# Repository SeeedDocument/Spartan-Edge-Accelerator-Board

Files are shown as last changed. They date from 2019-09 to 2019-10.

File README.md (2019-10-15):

---
name: Spartan Edge Accelerator Board
category: Platform
bzurl: 
oldwikiname: 
prodimagename:
surveyurl: 
sku: 102030005
tags:
---

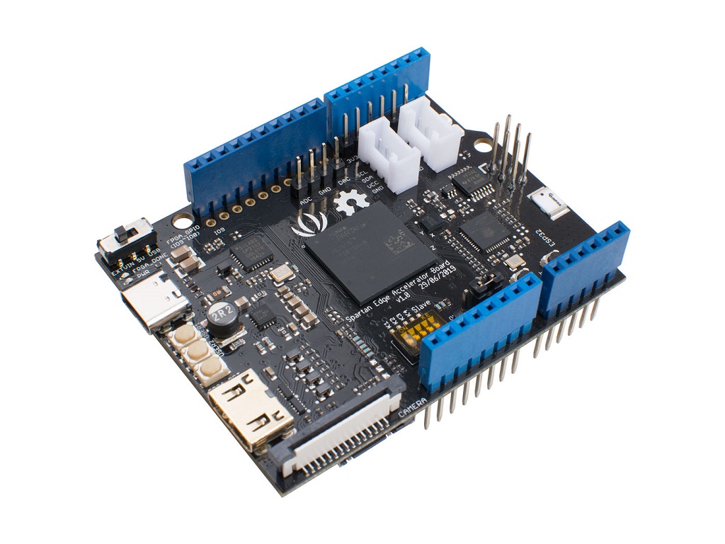
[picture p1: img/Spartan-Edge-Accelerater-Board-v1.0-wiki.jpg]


The Spartan Edge Accelerator Board (SEA Board in short) is a lightweight FPGA development board, it is based on the Xilinx Spartan-7 chip and follows the Arduino shield form factor. Hence, you can use it as an Arduino shield to driver an LCD and a camera or as a stand-alone FPGA development board. Besides, with the help of on-board ESP32 chip, the SEA board also enables your Arduino with WiFi and Bluetooth function.

**Spartan-7** is the newest and most cost-effective FPGA chip among Xilinx’s FPGA family, offers the best in class performance per watt. 

On top of that, we provide the full FPGA APIs for Arduino, which means Arduino users are able to use the FPGA function without knowing anything about FPGA. This board will broaden Arduino’s capability in many ways like simple image processing and computer vision application, signal encryption and decryption, and signal sampling and processing. 

## Features

- Full FPGA APIs for Arduino
- Stand alone mode/Arduino Shield mode
- On-board WiFi and bluetooth 4.1 with BLE
- On-board 8 bit ADC
- On-board 6 axis Accelerometer and Gyroscope
- On-board Grove Connector(I2C/D2)

## Specification

|Parameter|Value|
|---|---|
|**FPGA**||
|FPGA Chip|Spartan-7 XC7S15|
|Logic Cells|12,800|
|Slics|2000|
|CLB Flip-Flops|16,000|
|Max. Distributed RAM (Kb)|150|
|Block RAM/FIFO w / ECC (36 kb each)|10|
|Total Block RAM (Kb)|360|
|Clock Mgmt Tiles (1 MMCM + 1 PLL)|2|
|DSP Slices|20|
|**Wireless**||
|Wireless Chip|Espressif ESP32-D0WDQ6|
|WiFi |802.11 b/g/n 2.4GHz|
|Bluetooth|Bluetooth 4.1 with BLE|
|**Peripheral**||
|Video|Mini HDMI x1|
|Camera|CSI/MIPI interface x1 (compatible with Raspberry Pi Camera V1 - OV5640)|
|SD card|Micro SD/TF card slot x1|
|FPGA GPIO|10 pins header (IO9~IO0)|
|Arduino GPIO|32 pins header (Arduino form factor)|
|Grove|Grove Connector x2 (I2C/D2)|
|LED|Monochrome LED x2<br>RGB LED x2|
|Button|Boot x1<br> Reset x1<br> FPGA Reset x1 <br> User x2|
|Switch|Power Mode Switch x1<br>5-Channel DIP Switch x1|
|**Power**||
|Operating Voltage|5V|
|IO Voltage|5V|
|Power Mode|USB Type C 5V<br>VIN 8~17V<br>Arduino Micro USB 5V|
|**Others**||
|ADC|8 bit ADC1173|
|Accelerometer and Gyroscope|6-axis LSM6DS3TR |

!!!Attention
    The SEA shield's IO voltage is 5V, and the FPGA's IO voltage is 3.3V, so we made a voltage divider to make the IOs voltage compatible. The 3.3V IO voltage of the SAM D21 series will be less than 3.3V after voltage division, which is not enough to drive the FPGA's IO. Therefore, at present, the SEA development board only supports the 5V IO Arduino board, such as [Arduino UNO](https://www.seeedstudio.com/Arduino-Uno-Rev3-p-2995.html) and [Seeeduino V4.2](https://www.seeedstudio.com/Seeeduino-V4-2-p-2517.html).

## Hardware Overview

<div align="center">
<figure>
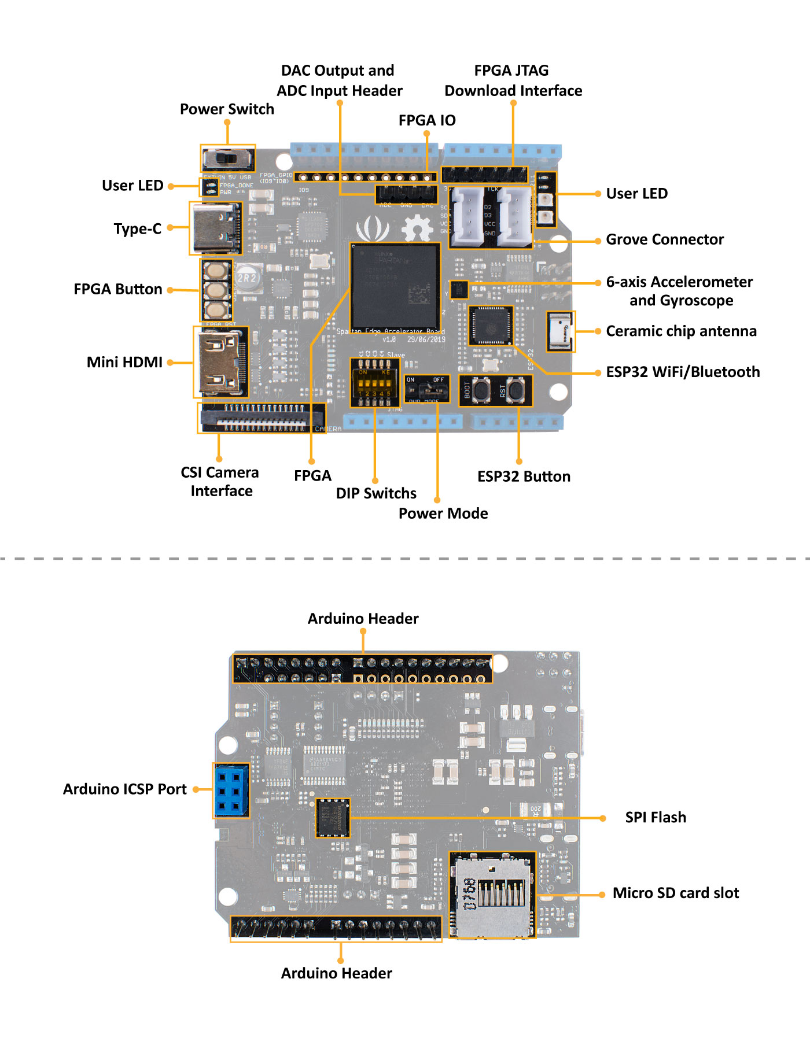
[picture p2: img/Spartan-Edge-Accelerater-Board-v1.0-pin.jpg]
Hardware Overview of SEA Board
  <a href="https://raw.githubusercontent.com/SeeedDocument/Spartan-Edge-Accelerator-Board/master/img/Spartan-Edge-Accelerater-Board-v1.0-pin.jpg" target="_blank">
  <figcaption><b>Figure 1</b>. <i>Hardware Overview of SEA Board</i></figcaption></a>
</figure>
</div>

|Number|Detail|
|-----|---|
|1.|FPGA : XC7S15-1FTGB196C|
|2.|WiFi/Bluetooth : ESP32-D0WDQ6|
|3.|6-axis Accelerometer and Gyroscope : LSM6DS3TR |
|4.|DAC : DAC7311IDCKR|
|5.|Buck-DCDC : TPS62130|
|6.|USB-to-UART : CP2102-GMR|
|7.|USB : Type-C |
|8.|Mini HDMI|
|9.|CSI Interface ：MIPI Camera (compatible with Raspberry Pi Camera V1 - OV5640)|
|10.|Arduino Header : Compatible with Arduino UNO|
|11.|DIP Switchs :<br>K1-K4 user switchs<br>K5 Switch FPGA Programming Mode <br>  ->>>> JTAG : Using Xilinx official Programming Tool<br>->>>> Slave : [Using ESP32 to Program the FPGA](https://github.com/sea-s7/spartan-edge-esp32-boot) |
|12.|ESP32 Button ：Boot and RST|
|13.|FPGA Button ：USER1 USER2 FPGA_RST|
|14.|User LED: L1/L2/RGB1/RGB2<br>PWR : Power On <br> FPGA_DONE : Light up after programming the FPGA with esp32.|
|15.|Power Switch :<br> USB->Powered by USB Type C (5V DC)<br>5V->Powered by VIN Pin (8~17V DC)|
|16.|Power Mode:<br>OFF->Isolate the power supply of Arduino and Shield<br>ON->Connect Power of Arduino and Shield|
|17.|DAC Output and ADC Input Header|
|18.|FPGA IO : IO9~IO0|
|19.|FPGA JTAG Download Interface|
|20.|Grove Connector : 1x I2C; 1x D2&D3|
|21.|Ceramic chip antenna|
|22.|ADC : ADC1173|
|23.|SPI Flash : W25Q32JVZPIG|
|24.|Analog Switch ：DG2788A|
|25.|LDO : XC6221B102MR|
|26.|LDO : RT9013-18GB|
|27.|LDO : CJ1117-3V3|
|28.|SD card slot : Micro SD/TF card|

## Getting Started

Spartan Edge Accelerator Board can work in two modes:

- Arduino shield Mode
- Stand-alone Mode

In brief, it can work as a Arduino shield to bring the Arduino FPGA and Wireless features, it also can work as a FPGA development board without an Arduino. 

### Arduino shield Mode

In this wiki, we use Seeeduino V4.2, you can also use Arduino UNO, they are fully compatible with each other.

#### Hardware

**Materials required**

- [Seeeduino V4.2](https://www.seeedstudio.com/Seeeduino-V4-2-p-2517.html) x1 
- [Spartan Edge Accelerator Board]() x1
- [Micro SD card or TF card](https://www.seeedstudio.com/micro-SD-Card-Card-with-Card-Reader-32GB-Class-10-p-4082.html) x1
- [USB Type C data cable](https://www.seeedstudio.com/USB-Type-C-to-A-Cable-1Meter-p-4085.html) x1

**Hardware Connection**

- Step1. Insert the Micro SD card or TF card into the SD card slot
- Step2. Plug the SEA Board into the Arduino
- Step3. Use one of the following three methods to power the system

|Power Port|Input Voltage|Power Switch Position|Power Mode Position|
|---|---|---|---|
|Powered by SEA board USB Type C port| 5V DC|USB|ON|
|Powered by Seeeduino V4.2 micro USB port| 5V DC|--|ON| 
|Powered by Seeeduino V4.2 DC port| 8~17V DC|5V|ON|

<div align="center">
<figure>
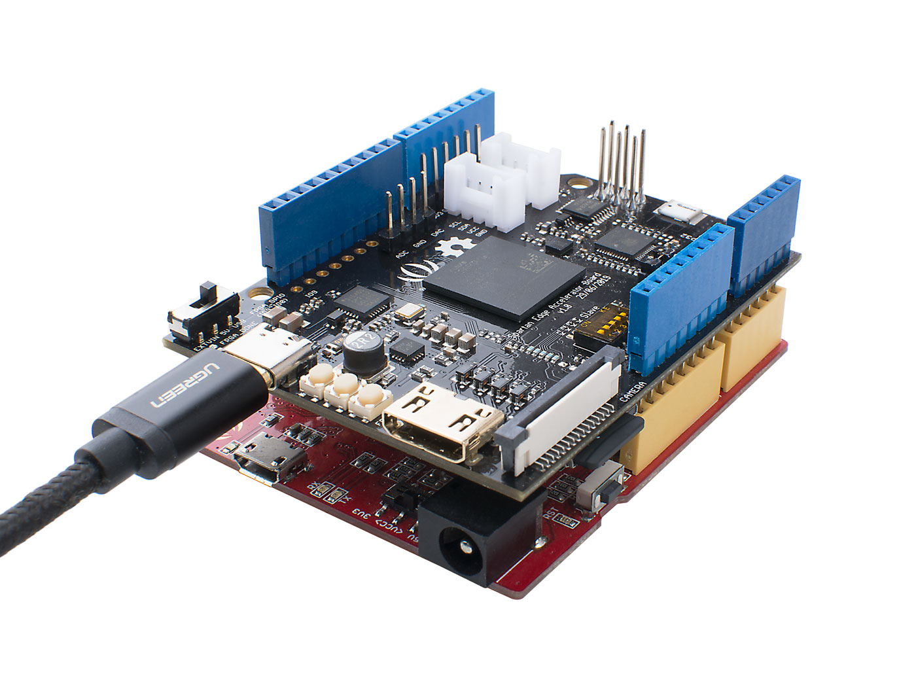
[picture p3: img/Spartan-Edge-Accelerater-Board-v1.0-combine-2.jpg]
Spartan Edge Accelerator Board Work with Arduino
  
  <figcaption><b>Figure 2</b>. <i>SEA board Work with Arduino</i></figcaption>
</figure>
</div>

!!!Attention
    You can also power both the SEA board and the Arduino at the same time, but please make sure you have set the Power Mode Position to **OFF**. Only then, the system power will be isolated, and you can power the Arduino and SEA board separately.

-------

#### Spartan Edge Accelerator Board ESP32 Boot

Firstly, to work with Arduino, we should load bitstream(FPGA Logic) from SD Card to the on-board FPGA(xc7s15). The following library will show you how to do this via on-board ESP32.

a library for Spartan Edge Accelerator Board

The purpose of this library is to load bitstream(FPGA Logic) from SDCard to the on-board FPGA(xc7s15) by the on-board ESP32.

The software development environment is [Arduino IDE](https://www.arduino.cc/en/Main/Software) with [ESP32 Boards support](https://github.com/espressif/arduino-esp32).

Since Version 1.6.4, Arduino allows installation of third-party platform packages using Boards Manager. We have packages available for Windows, Mac OS, and Linux (32 and 64 bit).

- Install the current upstream Arduino IDE at the 1.8 level or later. The current version is at the [Arduino website](http://www.arduino.cc/en/main/software).
- Start Arduino and open Preferences window.
- Enter ```https://dl.espressif.com/dl/package_esp32_index.json``` into *Additional Board Manager URLs* field. You can add multiple URLs, separating them with commas.
- Open Boards Manager from Tools > Board menu and install *esp32* platform (and don't forget to select your ESP32 board from Tools > Board menu after installation).
- select ___tool->board->DOIT ESP32 DEVKIT___   

Stable release link: `https://dl.espressif.com/dl/package_esp32_index.json`  
Development release link: `https://dl.espressif.com/dl/package_esp32_dev_index.json`  
If you want more details, you can click the [link](https://github.com/espressif/arduino-esp32)

<br>

##### Library Usage

- **1.Download the ESP32 Boot Library**

<div align="center">
<figure>
  
</figure>
</div>

Then add this library to your Arduino IDE.

If you don't know how to install the library, please kindly check:  
 
 [Installing Additional Arduino Libraries](https://www.arduino.cc/en/Guide/Libraries)

 You can find two example folders in this library

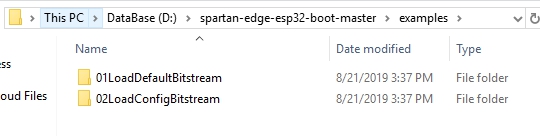
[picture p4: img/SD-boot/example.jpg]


|Example|Description|
|----|----|
|01LoadDefaultBitstream |This example will load SDCard file /overlay/default.bit to FPGA|
|02LoadConfigBitstream |This example will read a ini format file /board_config.ini in SDCard,then load the bitstream spcified by the value of key **overlay_on_boot** to FPGA.|

- **2.Prepare SDCard**  
  2.1 Format the SDCard with FAT16/FAT32 filesystem.  

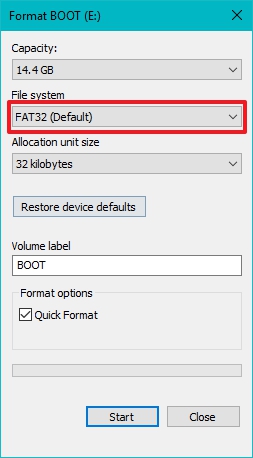
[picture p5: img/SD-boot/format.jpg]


  2.2 Create a top level subfolder named __overlay__ in the SDCard.  
  2.3 Put your bitstream or [sample bitstream](https://github.com/sea-s7/AlphaTest_V1.0/tree/master/spi2gpio) files (must have a extend name .bit) into the folder __overlay__.  

!!!Tip
    The sample bitsteam : GPIO extension controlled by SPI interface, with support of ADC/DAC/RGB-LED, see [source code](https://github.com/sea-s7/Demo_project/tree/master/spi2gpio).

  2.4 If you run example 01LoadDefaultBitstream, rename the bitstream file in __overlay__ to __default.bit__.  



  2.5 If you run example 02LoadConfigBitstream, put [**board_config.ini**](https://github.com/sea-s7/spartan-edge-esp32-boot/blob/master/extras/board_config.ini) into SDCard root folder.  
  2.6 Insert the SDCard to the Spartan (Edge Accelerator) Board.  

- **3.Upload example**  
  3.1 Connect the Spartan Board through USB Type-C wire to the PC, and install USB232 driver (chip CP2102).  
  3.2 Turn the power switch (near the USB Type-C slot) to USB side to power on the board.  
  3.3 Open one of the library examples by Arduino IDE.  
  3.4 Check Board & Port setting in Arduino IDE as described in last section.  
  3.5 Press 'BOOT' Button on Sparton Board and last more than 1 seconds to force ESP32 enter Bootloader mode.  
  3.6 Press 'Upload' button in Arduino IDE to upload the example ('s compiled binary) to ESP32.  

- **4.Run example**  
  4.1 Make sure the on-board DIP-switch K5 (last one) on Slave(ON) side, which enable FPGA programing by other device(MCU).  
  4.2 Press 'RST' button on Spartan Board to startup the example.  
  4.3 After the example bootup a few seconds, the FPGA_DONE(red color) LED on the board will light on.

------

#### Spartan Edge Accelerator Board IO Example

Then, the following tutorial will show you how to control the GPIO/ADC/DAC/RGB-LED resources of Spartan Edge Accelerator Board with Arduino.

- Download the IO Example Library:

<div align="center">
<figure>
  
</figure>
</div>

- Add this library to your Arduino IDE. If you don't know how to install the library, please kindly check:  

 [Installing Additional Arduino Libraries](https://www.arduino.cc/en/Guide/Libraries)

- Located to the `examples` folder, choose any example, double cilck the .ino file.

- Upload the demo. If you do not know how to upload the code, please check [How to upload code](http://wiki.seeedstudio.com/Upload_Code/).

### Stand-alone Mode

#### Hardware

**Materials required**

- [Spartan Edge Accelerator Board]() x1
- [USB Type C data cable](https://www.seeedstudio.com/USB-Type-C-to-A-Cable-1Meter-p-4085.html) x1

Just power the Spartan Edge Accelerator Board via the USB Type C cable.

#### Software

Spartan Edge Accelerator Board can also work as a traditional FPGA development board. The following traditional will show you how to use it at the stand-alone mode.

In this section, you will learn about the Project mode features for project creation, source file management, design analysis, constraint definition, and synthesis and implementation run management. This could be used as a quick reference.

First of all, you should download the vivado tutorial library, we will need some sorce files.

<div align="center">
<figure>
  
</figure>
</div>

- **Step 1: Creating a Project**   

  *Launching Vivado*

  *Creating a New Project*

1. After Vivado opens, select **Create Project** on the Getting Started page.

2. Click **Next** in the New Project wizard

3. Specify the Project Name and Location (Select “**Create project subdirectory**” to create a folder for your project) 

4. Click **Next**.

5. Select **RTL Project** as the **Project Type** and click **Next**.(Select **Do not specify sources at this time** and add your files soon afterwards)

   *(The Vivado Design Suite allows for different design entry points depending on your source file types and design tasks. You can choose the suitable type of project.)*

6. Select the **xc7s15ftgb196-1** part for project, and click Next, as shown in figure 1.

7. Click **Finish**

<div align="center">
<figure>
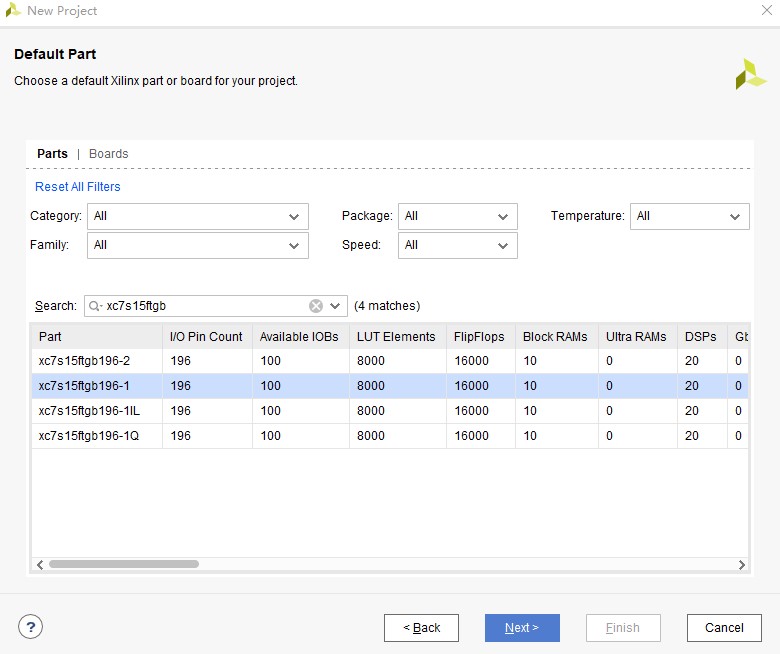
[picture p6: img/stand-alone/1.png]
  
    <div class="text"><b>Figure 1.</b></div>
</figure>
</div>

The Vivado IDE opens project_tutorial in the default layout, as shown in figure 2.

<div align="center">
<figure>
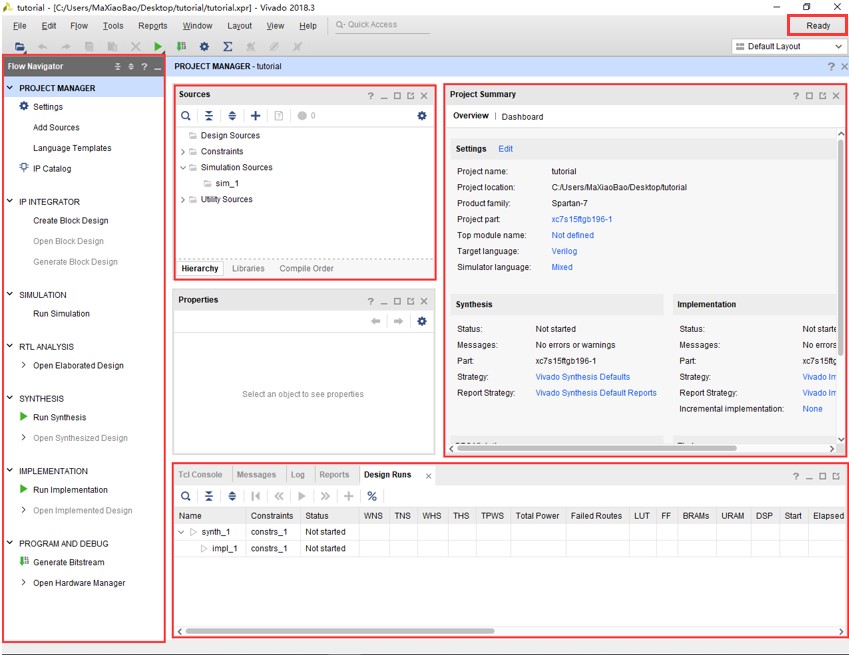
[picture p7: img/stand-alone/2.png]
  
  <div class="text"><b>Figure 2.</b></div>
</div>

The **Flow Navigator** shows the basic design process clearly.

The **Sources** is made up of **Constraints**, **Simulation** **Sources** and **Utility** **Sources**.

The **Design Runs** creates synth_1 and impl_1 by default.

The **running status** of vivado is displayed in the upper right corner.

- **Step 2: Add and Create Your Files** 

  *in this step, we add **test.v** , **test_pin.xdc** , **test_sim.v** in our project. These files are located in different folders of **vivado_tutorial/vivado_tutorial.srcs*** 

1. Click **Add Sources** in the **PROJECT MANAGER** of the Flow **Navigator** to add **RTL file**.

2. Select **Add or create design sources** and click Next.

3. Click the button  and select options or click the options directly to add or create files, as shown in figure 3.

<div align="center">
<figure>
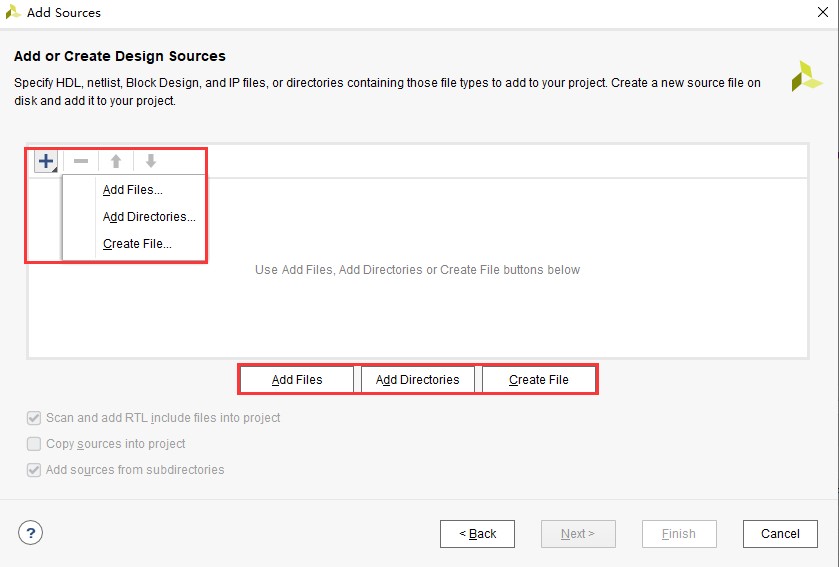
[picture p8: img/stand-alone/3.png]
  
  <div class="text"><b>Figure 3.</b></div>
</figure>
</div>

4. Here, we add RTL files directly. Select **Add Files** and add file **test.v** in your directory, as shown in figure 4.

<div align="center">
<figure>
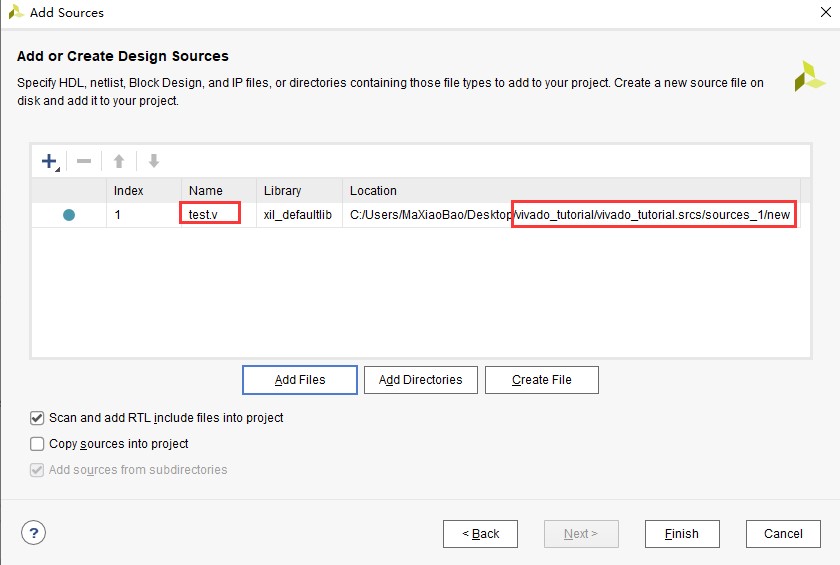
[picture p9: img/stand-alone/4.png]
  
  <div class="text"><b>Figure 4.</b></div>
</figure>
</div>

5. Click **Finish**.

6. Click **Add Sources** in the **PROJECT MANAGER** of the Flow **Navigator** again to add **constraints file**.

7. Select **Add or create constraints** and click Next. 

8. Click **Add Files** and add your constraints file **test_pin.xdc** ,as shown in figure 5

    <div align="center">
    <figure>
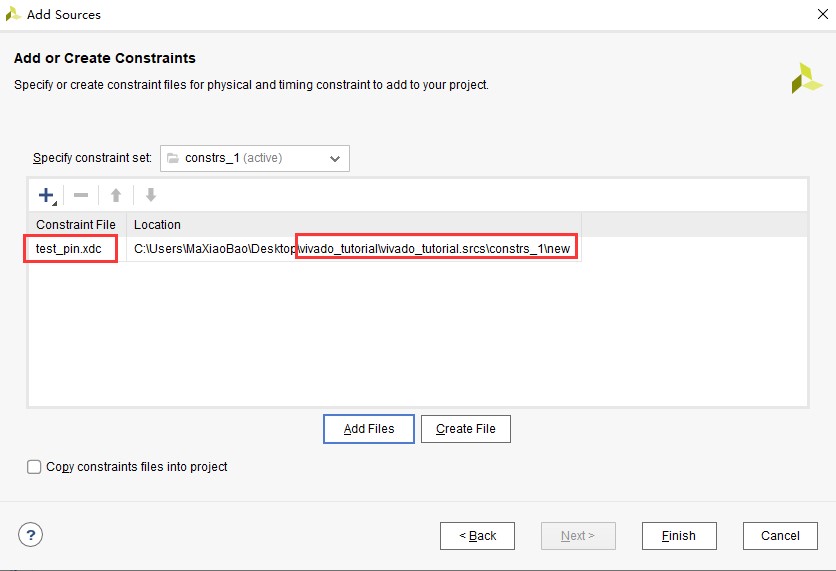
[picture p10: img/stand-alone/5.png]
      
      <div class="text"><b>Figure 5.</b></div>
    </figure>
    </div>

9. Click **Finish**.

10. Click **Add Sources** in the **PROJECT MANAGER** of the Flow **Navigator** again to add **simulation file**.

11. Select **Add or create simulation sources** and click Next. 

12. Click **Add Files** and add your simulation file **test_sim.v** ,as shown in figure 6

     <div align="center">
     <figure>
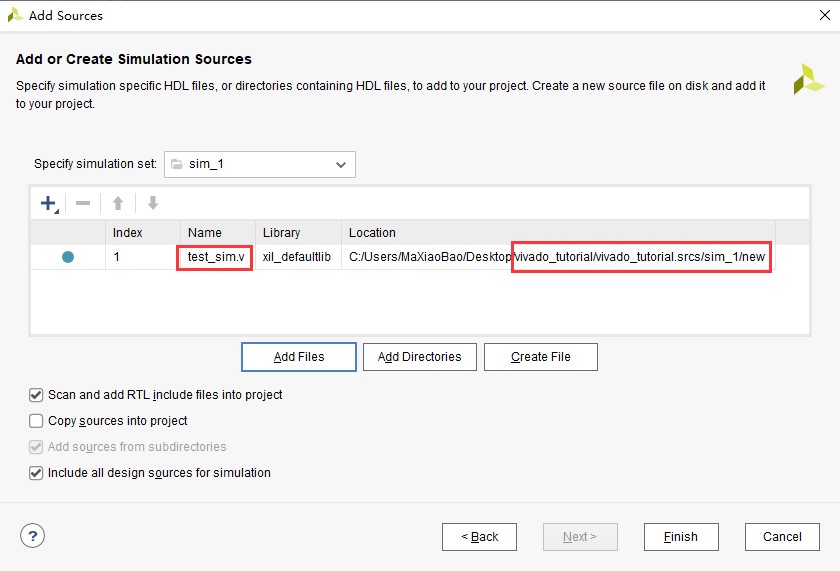
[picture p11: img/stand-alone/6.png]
       
       <div class="text"><b>Figure 6.</b></div>
     </figure>
     </div>

13. Click **Finish**.

     Finally, the file we added will appear in the **Sources**, as shown in figure 7.

<div align="center">
<figure>
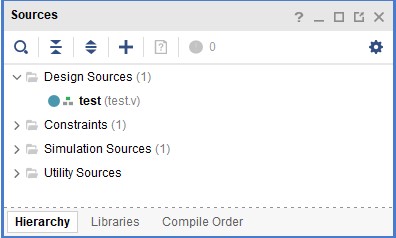
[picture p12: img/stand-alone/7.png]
  
   <div class="text"><b>Figure 7.</b></div>
</figure>
</div>

- **Step 3: Elaborating the RTL Design**

  The Vivado IDE includes an RTL analysis and IP customizing environment. There are also several RTL Design Rule Checks (DRCs) to examine ways to improve performance or power on the RTL design.

1. Select Open Elaborated Design in the Flow Navigator to elaborate the design.

2. Ensure that the Layout Selector pull down menu in the main Toolbar has Default Layout selected. The Elaborated Design enables various analysis views including an RTL Netlist, Schematic, and Graphical Hierarchy. The views have a cross-select feature, which helps you to debug and optimize the RTL.

3. Explore the logic hierarchy in the RTL Netlist window and examine the Schematic. You can traverse the schematic by double-clicking on cells to push into the hierarchy, or by using commands like the Expand Cone or Expand/Collapse from the Schematic popup menu. 

4. Select any logic instance in the Schematic and right-click to select the **Go to Source** or **Go to Definition** commands.

5. Click the Messages window at the bottom of the Vivado IDE, and examine the messages.

6. Click the **Collapse All** button in the Messages toolbar.

7. Expand the Elaborated Design and the messages, as shown in figure 8.

<div align="center">
<figure>
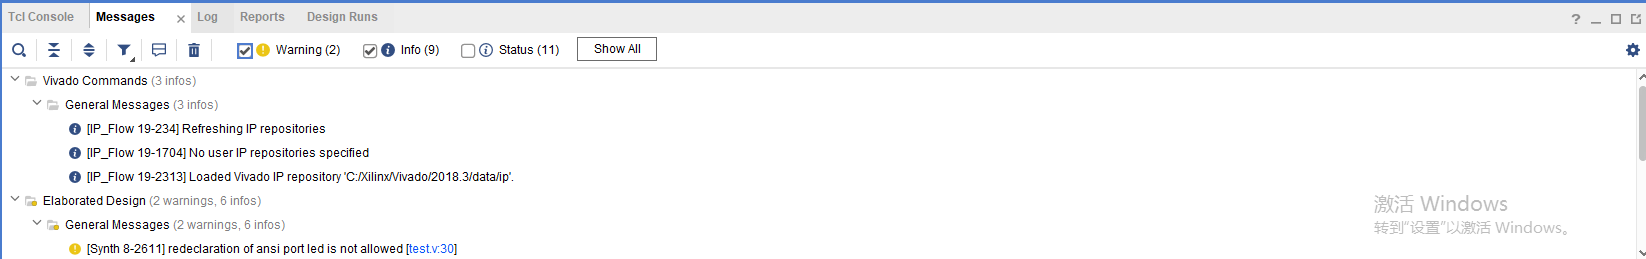
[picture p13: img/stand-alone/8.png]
  
   <div class="text"><b>Figure 8.</b></div>
</figure>
</div>

8. Click one of the links and the Text Editor opens the RTL source file with the relevant line highlighted.
9. Close the Text Editor windows.
10. Close the Elaborated Design by clicking on the **X** on the right side of the Elaborated Design window banner, and click OK to confirm.

- **Step 4: Using the IP Catalog**

  The Xilinx IP Catalog provides access to the Vivado IP configuration and generation features. You can sort and search the Catalog in a variety of ways. IP can be customized, generated, and instantiated.

1. Click the **IP Catalog** button in the Flow Navigator, under Project Manager.

2. Browse the IP Catalog to examine the various categories and IP filtering capabilities.

3. Choose the corresponding IP and perform native customization and configuration of IP within the tool and select **OK**

4. Close the IP Catalog tab by clicking on the X on the window tab.

- **Step 5: Running Behavioral Simulation**

  The Vivado IDE integrates the Vivado Simulator, which enables you to add and manage simulation sources in the project. You can configure simulation options, and create and manage simulation source sets. You can run behavioral simulation on RTL sources, prior to synthesis.

1. In the Flow Navigator, under Project Manager, click the Settings command. The Settings dialog box opens with Project Settings at the top, and Tool Settings below that, as shown in figure 9.

<div align="center">
<figure>
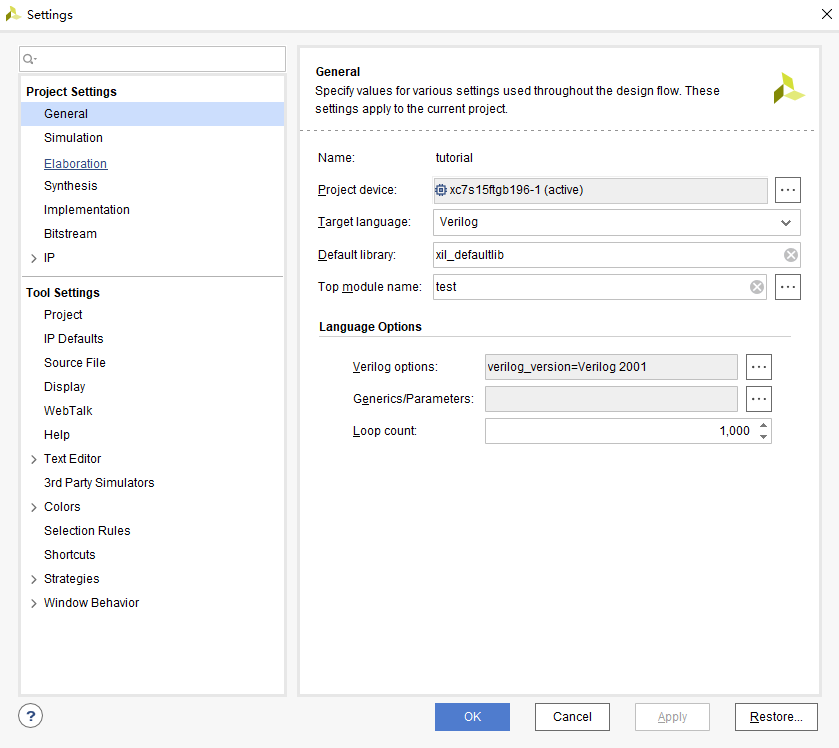
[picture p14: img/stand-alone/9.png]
  
  <div class="text"><b>Figure 9.</b></div>
</figure>
</div>

2. Examine the settings available on the **Simulation** page, then click **Cancel** to close the dialog box.
3. Click the **Run Simulation** command in the Flow Navigator, then click the **Run Behaviora Simulation** in the sub-menu, as shown in figure 10.

<div align="center">
<figure>
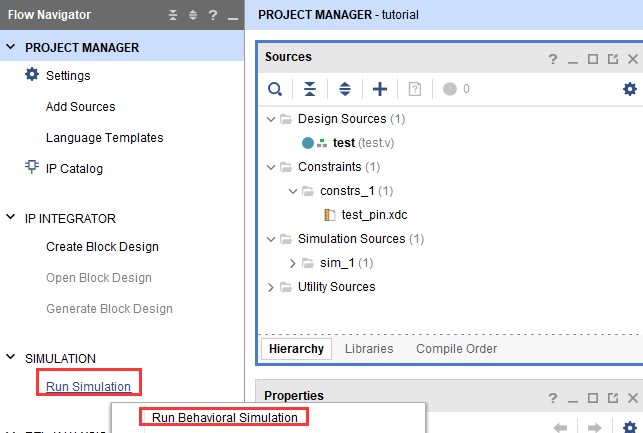
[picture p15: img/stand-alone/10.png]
  
  <div class="text"><b>Figure 10.</b></div>
</figure>
</div>

4. Drag the bar to the left and use these tools to zoom in or zoom out to see the appropriate image, as shown in figure 11 and figure 12.

   <div align="center">
   <figure>
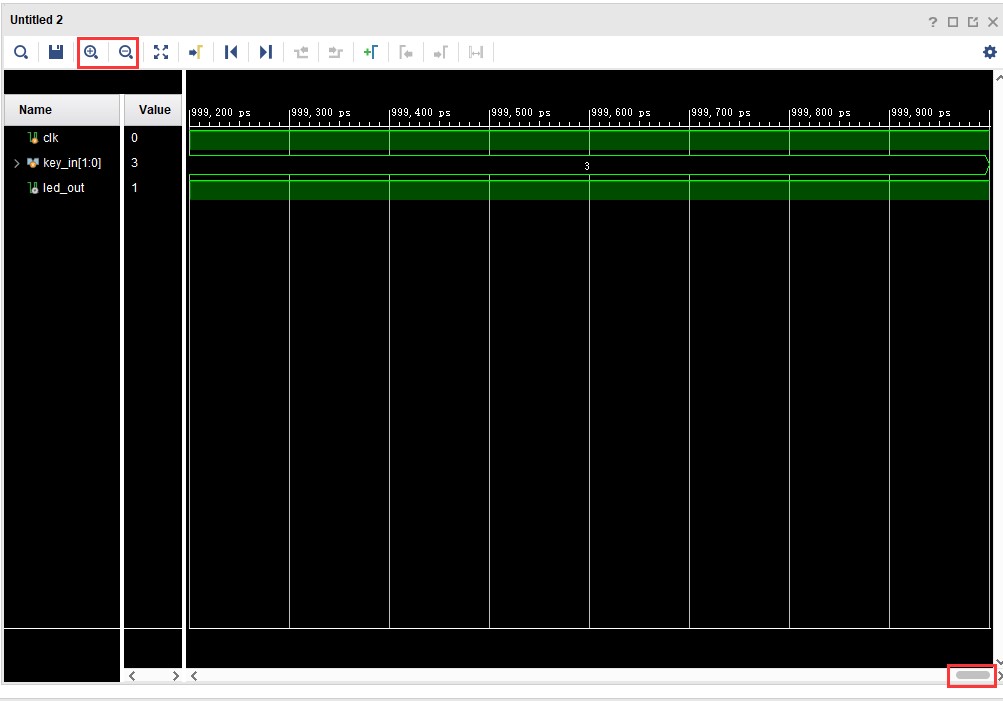
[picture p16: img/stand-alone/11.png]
     
     <div class="text"><b>Figure 11.</b></div>
   </figure>
   </div>

   <div align="center">
   <figure>
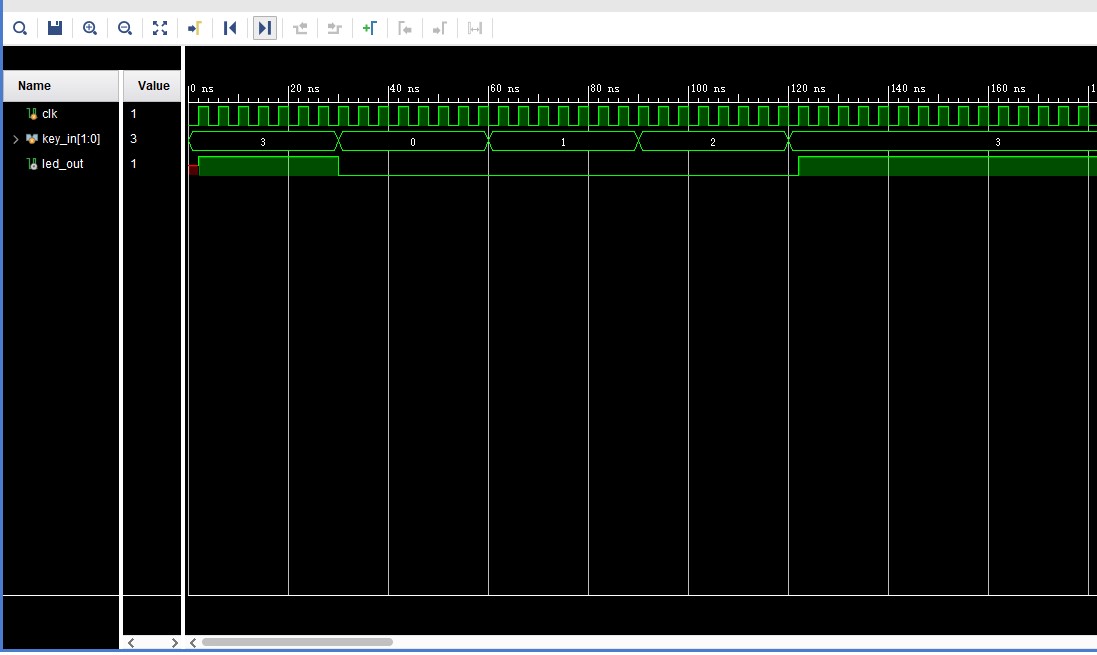
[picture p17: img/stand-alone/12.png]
     
     <div class="text"><b>Figure 12.</b></div>
   </figure>
   </div>

5. Click **X** on the Right-Up corner of figure 13 and click **OK** to close the SIMULATION.

   <div align="center">
   <figure>
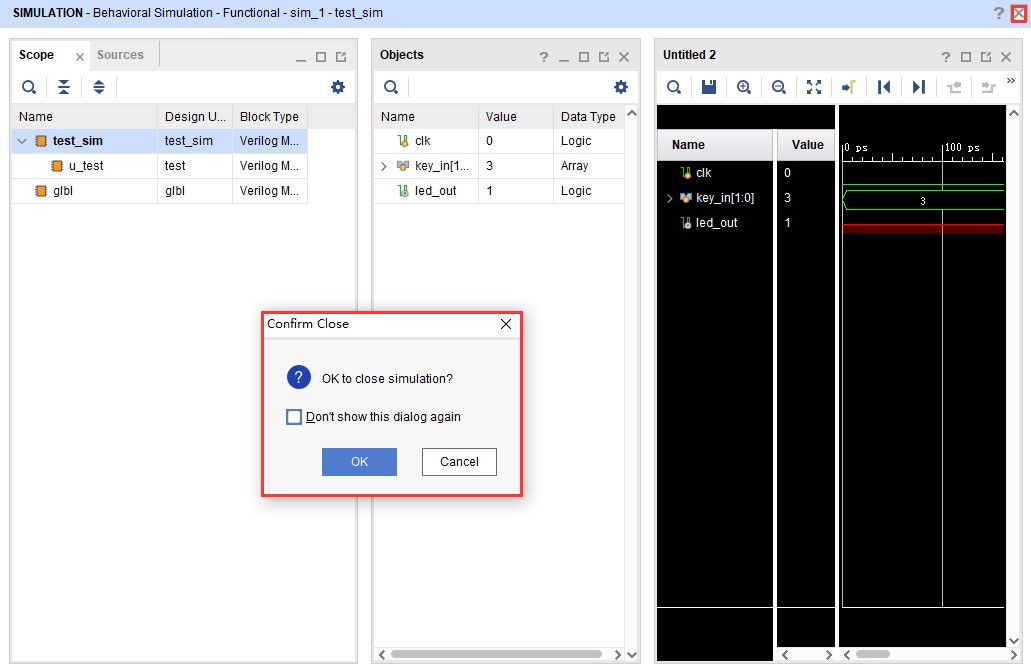
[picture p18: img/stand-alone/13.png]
     
     <div class="text"><b>Figure 13.</b></div>
   </figure>
   </div>

- **Step 6:  Reviewing Design Run Settings**

  Design runs are a way of configuring and storing the many options available in the different steps of the synthesis and implementation process. You can configure these options and save the configurations as strategies to be used in future runs.

1. In the Flow Navigator, under Project Manager, click the **Settings** command.

2. Select the **Synthesis** page under Project Settings. For a complete description of these options, see the *Vivado Design Suite User Guide: Synthesis*([UG901](https://www.xilinx.com/support/documentation/sw_manuals/xilinx2018_3/ug901-vivado-synthesis.pdf)).

3. Select the **Implementation** page under Project Settings. For a complete description of these options, see the *Vivado Design Suite User Guide: Implementation*([UG904](https://www.xilinx.com/support/documentation/sw_manuals/xilinx2018_3/ug904-vivado-implementation.pdf )).

- **Step 7: Synthesizing and Implementing the Design**

  After configuring the synthesis and implementation run options, you can **run synthesis** and **run implementation** in the **Design Runs** or click the button   or click corresponding buttons in the **Flow Navigator** to do this. The **running status** of vivado is displayed in the upper right corner while Synthesizing and Implementing.

	For this tutorial, we will run these steps in the Design Runs.

1. Right click the syth_1 and select **Launch Runs**, as shown in figure 14.

<div align="center">
<figure>
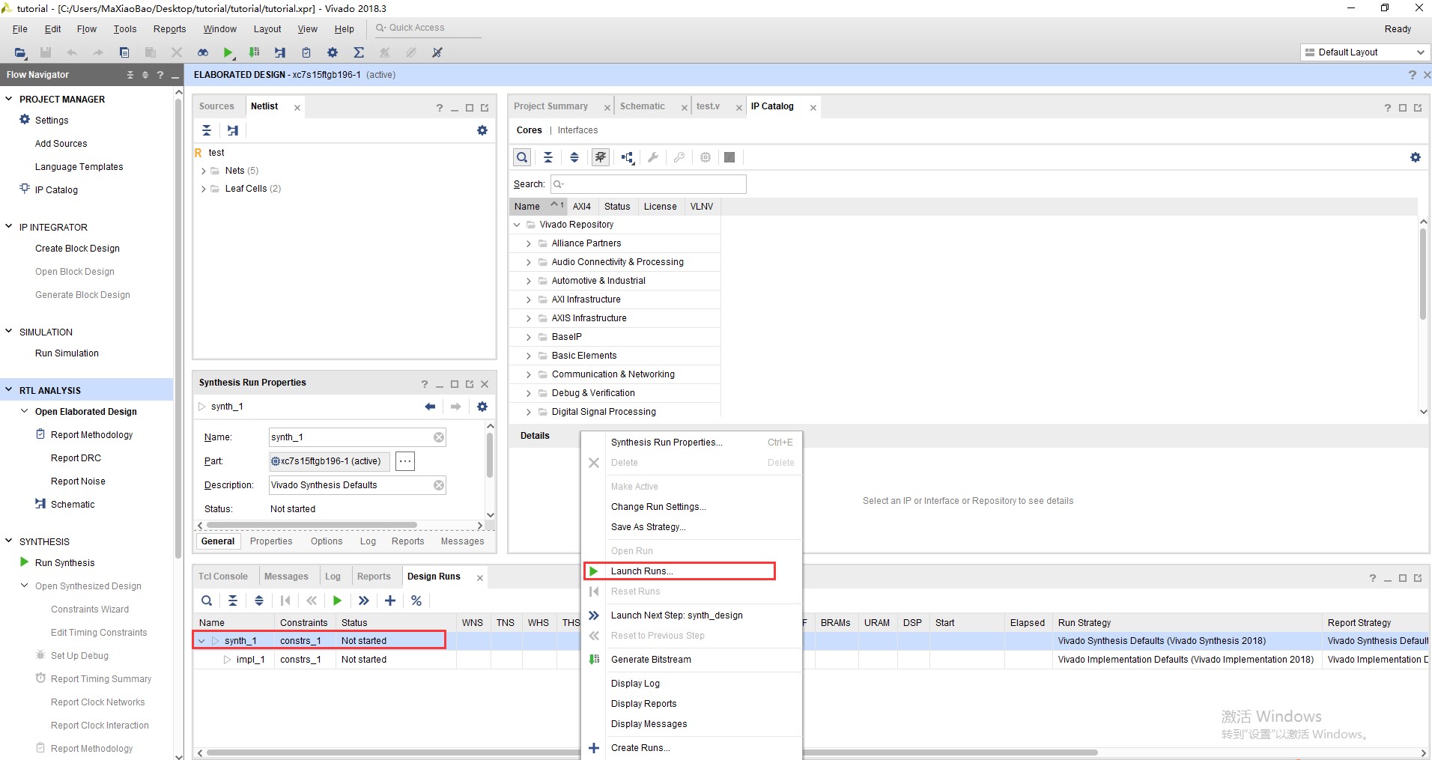
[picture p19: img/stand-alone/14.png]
  
  <div class="text"><b>Figure 14.</b></div>
</figure>
</div>

2. Click ok and running status is displayed in the upper right corner, as shown in figure 15.

<div align="center">
<figure>
  
  <div class="text"><b>Figure 15.</b></div>
</figure>
</div>

3. Click  **Open Synthesized Design** for further design and analysis. You can see **Report Timing Summary** , **Report Utilization** and others, as shown in figure 16.

<div align="center">
<figure>
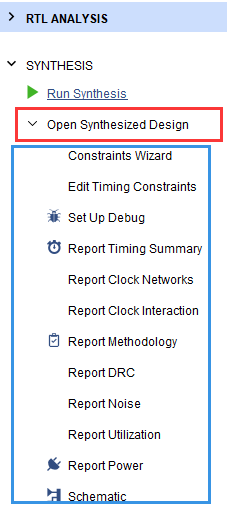
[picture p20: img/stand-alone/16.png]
  
  <div class="text"><b>Figure 16.</b></div>
</figure>
</div>

4. Run Implementation in the same way, as shown in figure 17.

<div align="center">
<figure>
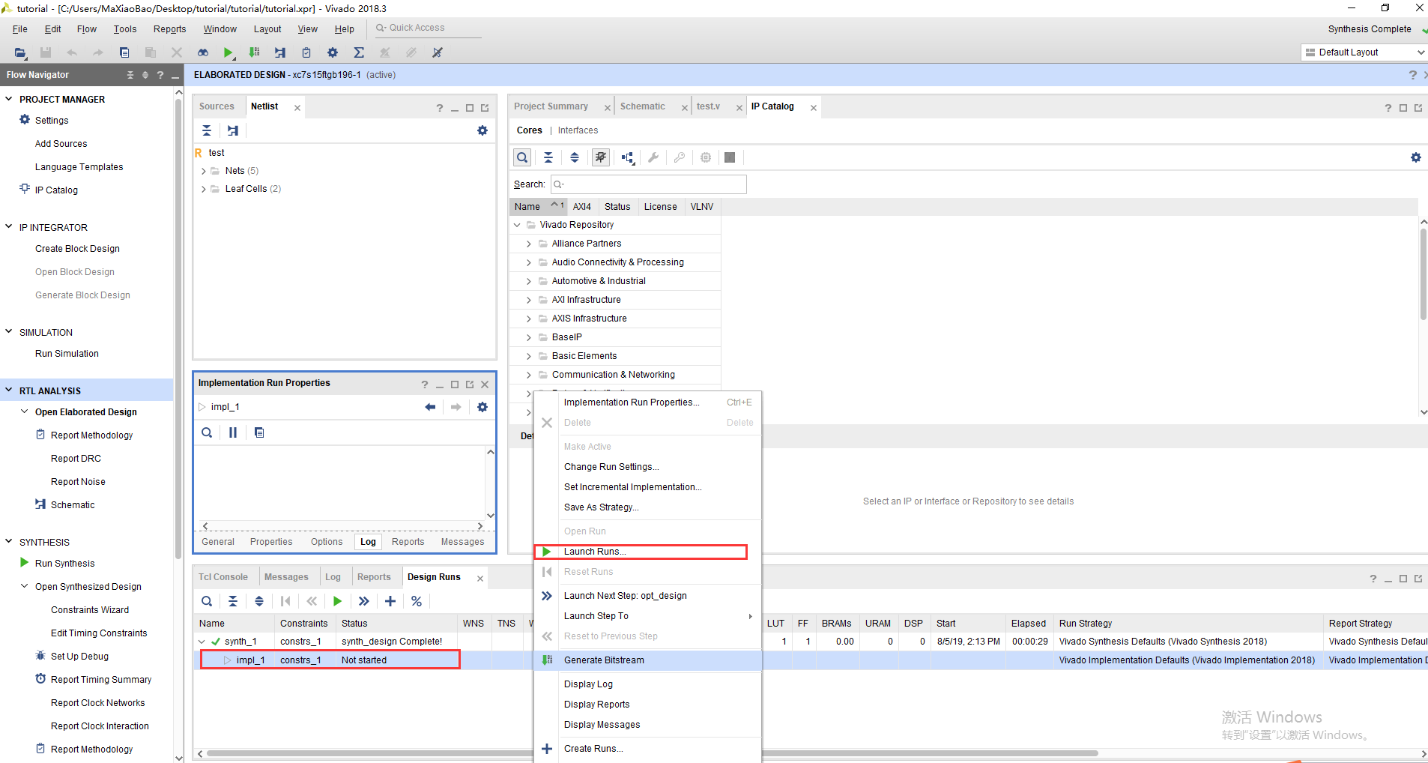
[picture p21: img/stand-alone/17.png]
  
  <div class="text"><b>Figure 17.</b></div>
</figure>
</div>

5. Click **Open implemented Design** to see reports after implementation 

- **Step 8: Generating a Bitstream File**

  After **Implementing the Design,** we can see synthesis and implement Complete in the **Design Runs**,as shown in figure 18.

<div align="center">
<figure>
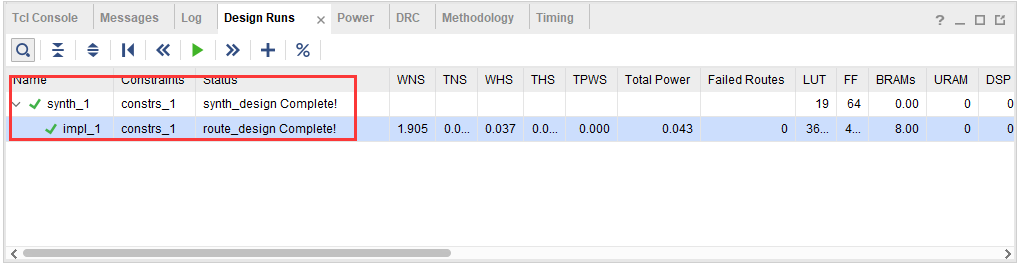
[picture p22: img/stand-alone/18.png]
  
  <div class="text"><b>Figure 18.</b></div>
</figure>
</div>

 Click **Generate Bitstream** in the Flow Navigator.

- **Step 9: Download the file** 

  After **Generate Bitstream,** you have two ways to load the file to FPGA. 

  You can use the JTAG interface(on the Right-Up corner of figure 19) to load the bit file to FPGA  in vivado, or    use the ESP32 (on the Right-Down corner of figure 19) to load the bit file to FPGA.

<div align="center">
<figure>
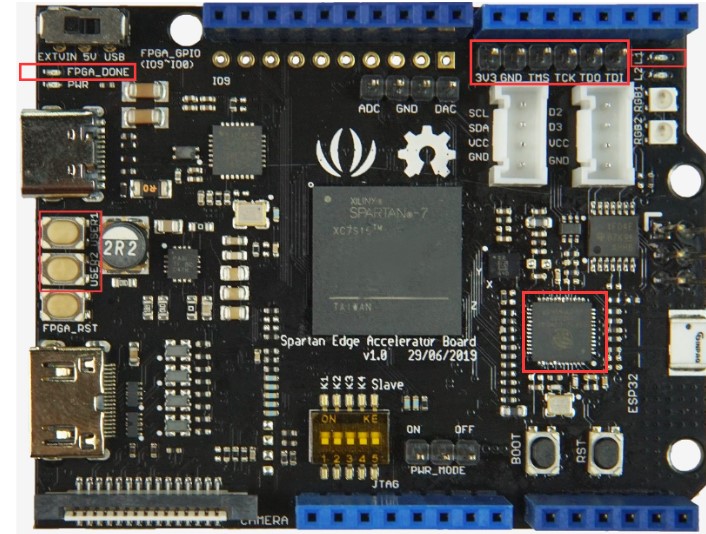
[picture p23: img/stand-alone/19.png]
  
  <div class="text"><b>Figure 19.</b></div>
</figure>
</div>

  **Follow below steps, to load bitstream to FPGA through JTAG interface**

1. Power the board and connect the [Platform Cable USB II](https://www.xilinx.com/products/boards-and-kits/hw-usb-ii-g.html)  (Or Compatible Cable).

2. Click **Open Target** and **Auto Connect** in the Flow Navigator.

3. While connect to the board successfully, click **Program Device** and choose the bit file and click **Program**, as shown in figure 20

<div align="center">
<figure>
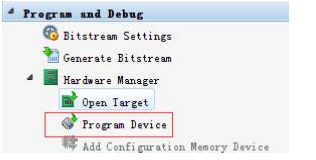
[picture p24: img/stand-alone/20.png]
  
  <div class="text"><b>Figure 20.</b></div>
</figure>
</div>

1. After download the bit file, the **FPGA**_**DONE** **led** will light.

   *In this project, if you press any key or both of them(**USER1** and **USER2**),  **LED L1**  will go out.*

## Resources

- **[PDF]** [Spartan-7 FPGAs Datasheet](https://github.com/SeeedDocument/Spartan-Edge-Accelerator-Board/raw/master/res/Spartan-7%20FPGAs%20Data%20Sheet.pdf)
- **[PDF]** [ESP32 Datasheet](https://github.com/SeeedDocument/Spartan-Edge-Accelerator-Board/raw/master/res/ESP32-datasheet.pdf)

## Tech Support
Please submit any technical issue into our [forum](http://forum.seeedstudio.com/).

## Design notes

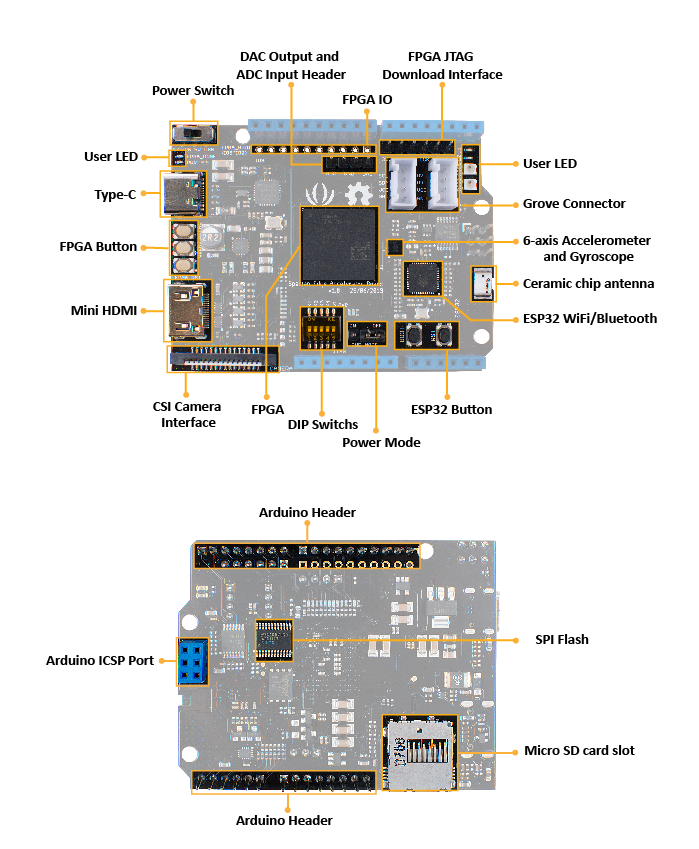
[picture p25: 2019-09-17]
img/hardware-overview.png

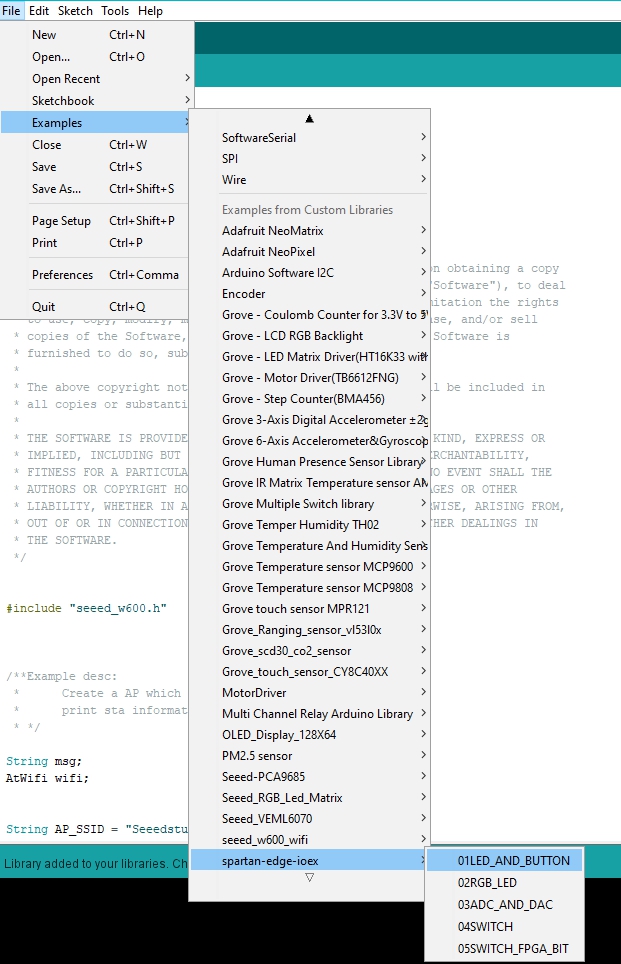
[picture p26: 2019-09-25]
img/IO-ex/example.jpg

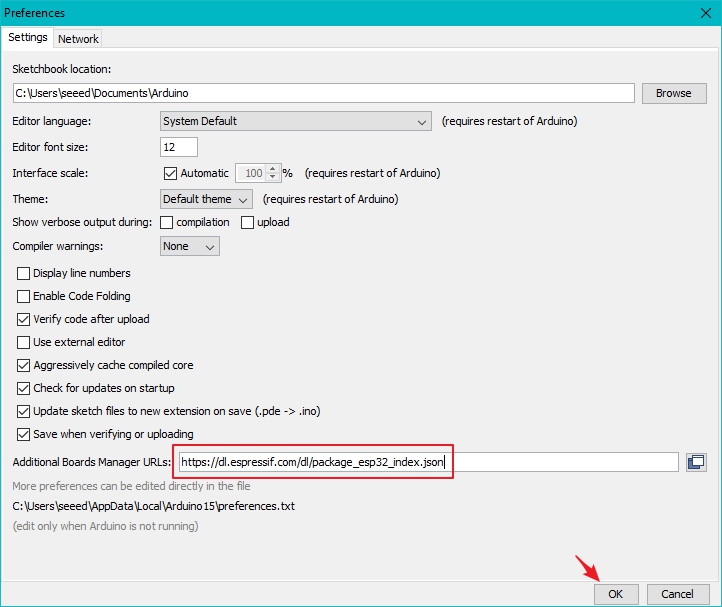
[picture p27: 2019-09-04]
img/boot-IDE-1.jpg

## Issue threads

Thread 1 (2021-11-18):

https://github.com/sea-s7 repository does not exist

richardklingler, 2021-11-18:
This board uses the spi2gpio Vivado design and the Wiki references to this repo:

https://github.com/sea-s7

But this repository doesn't seem to exist..so without the spi2gpio sources this board is useless!

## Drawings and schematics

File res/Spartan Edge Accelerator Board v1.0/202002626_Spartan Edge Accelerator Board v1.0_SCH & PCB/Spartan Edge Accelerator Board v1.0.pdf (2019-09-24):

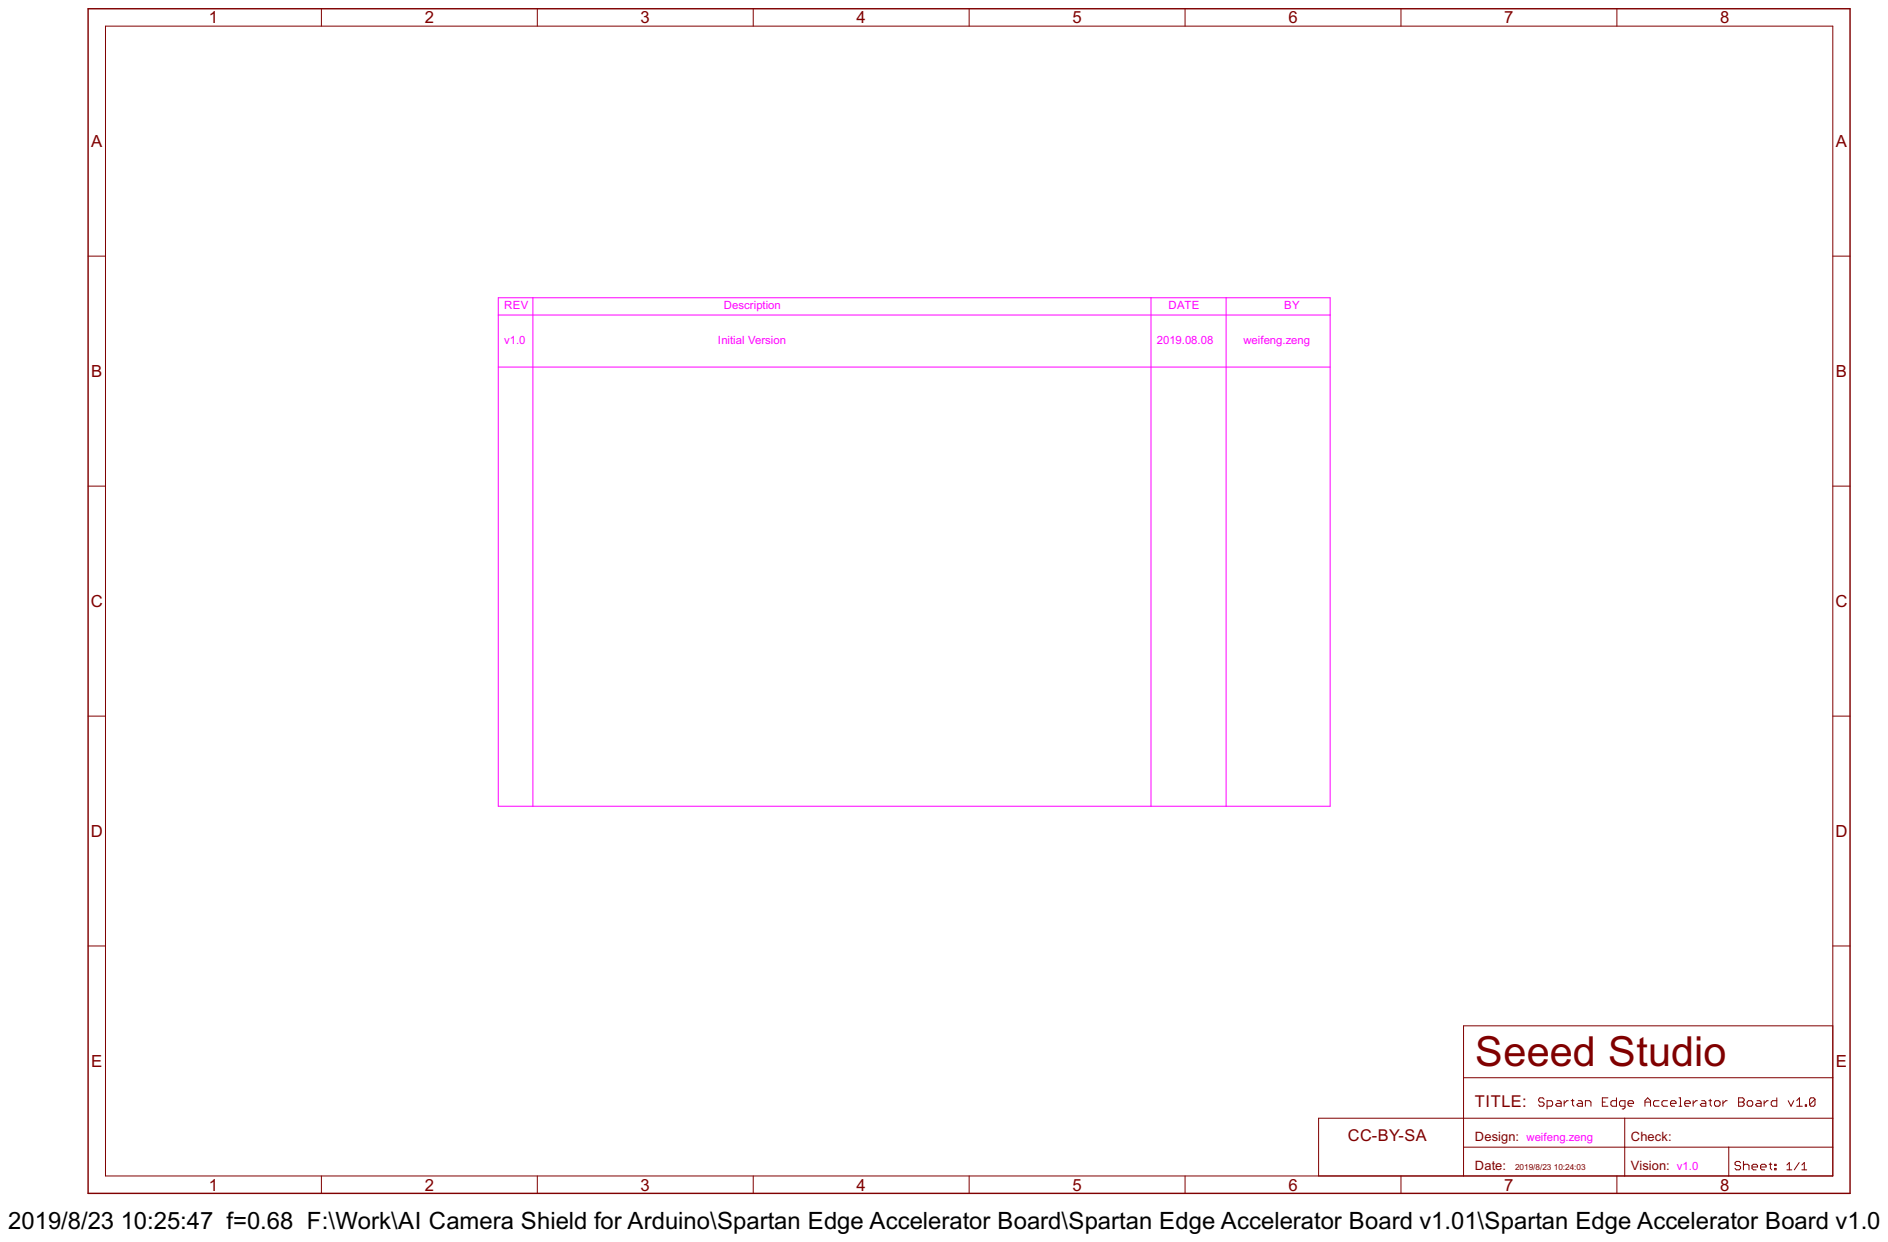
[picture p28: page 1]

REV | Description | DATE | BY

v1.0 | Initial Version | 2019.08.08 | weifeng.zeng

TITLE: Design: weifeng.zeng | Check: Date: Vision: CC-BY-SA

2019/8/23 10:25:47 f=0.68 F:\Work\AI Camera Shield for Arduino\Spartan Edge Accelerator Board\Spartan Edge Accelerator Board v1.01\Spartan Edge Accelerator Board v1.0\202002626_Spartan Edge Accelerator Board v1.0_SCH & PCB\Spartan Edge Accelerator Board v1.0.sch (Sheet: 1/1)

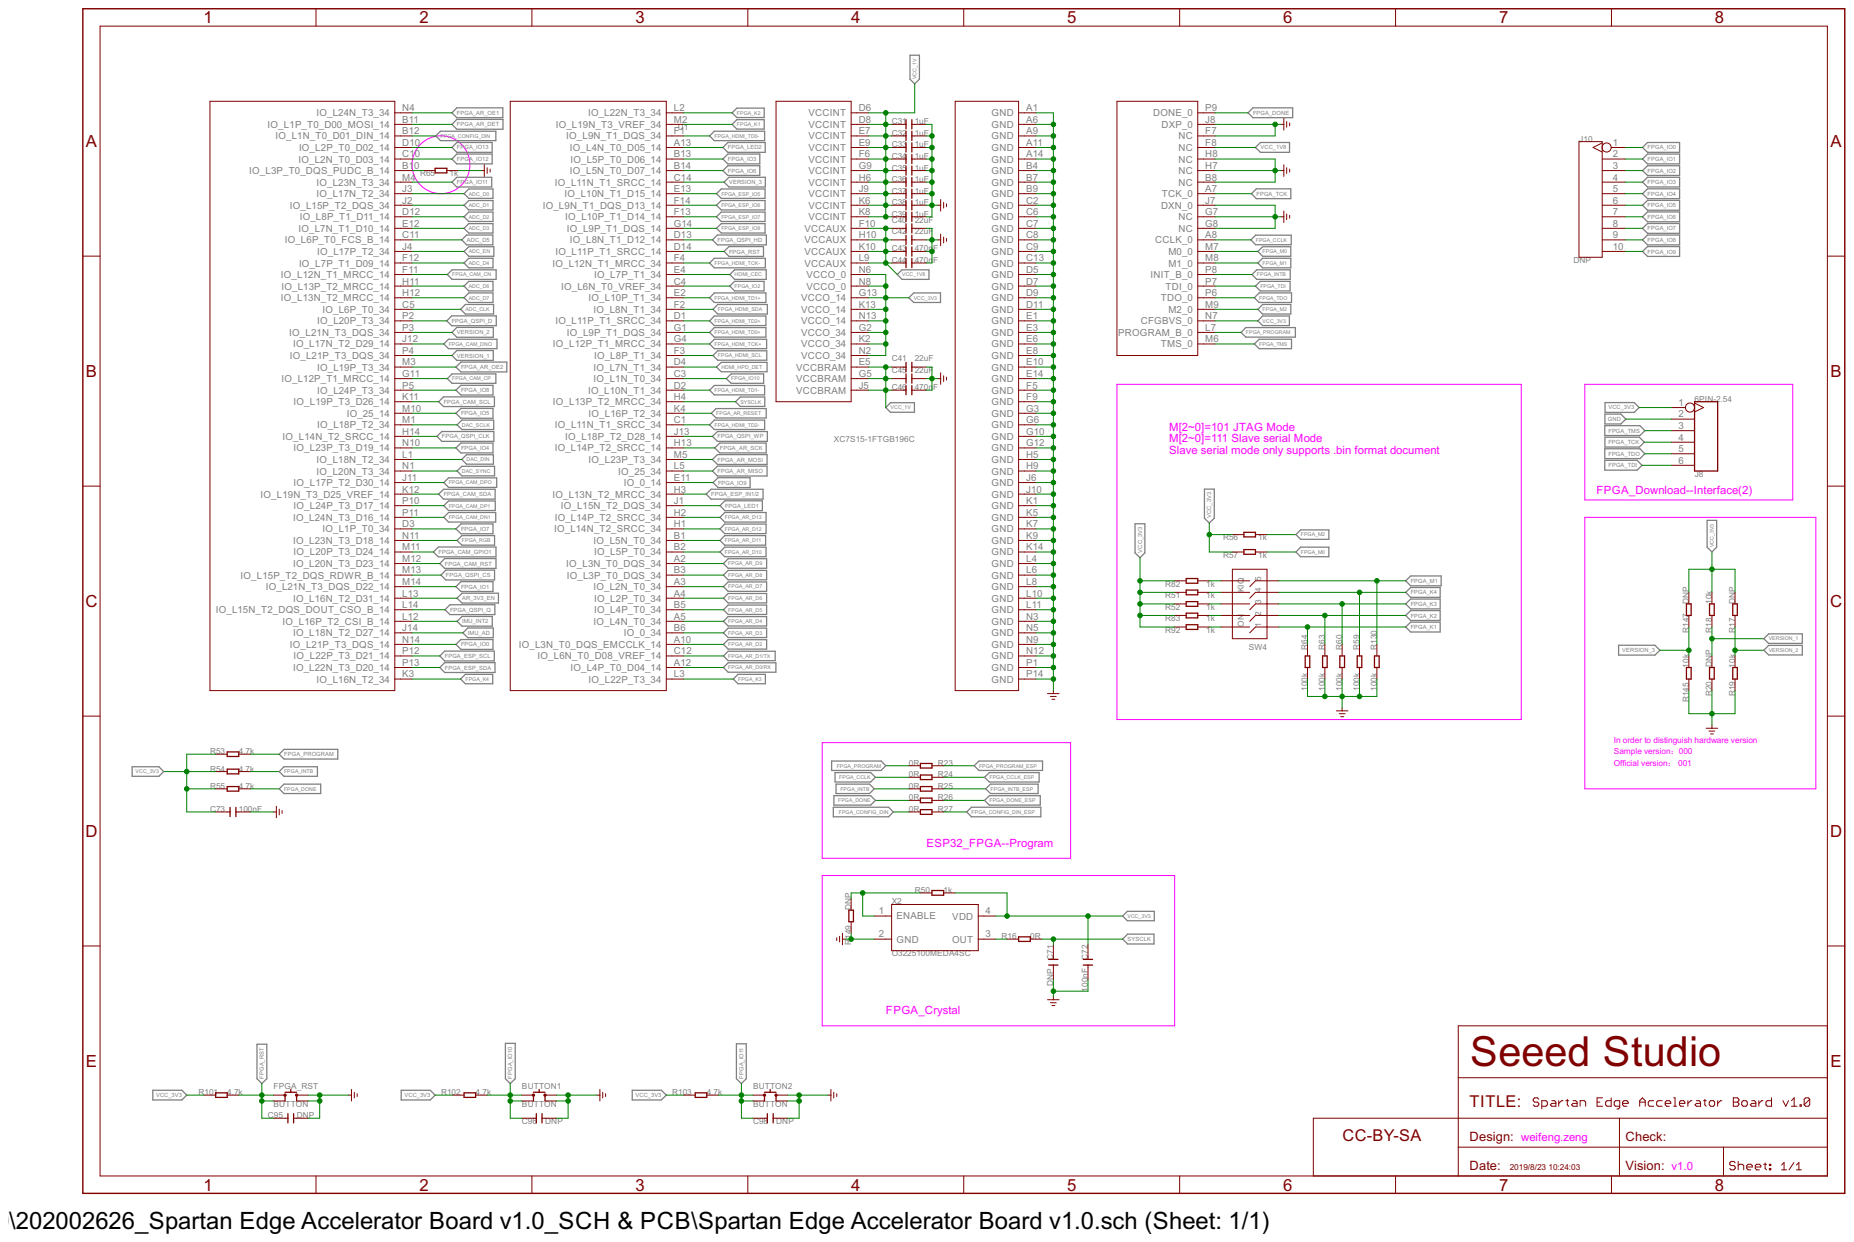
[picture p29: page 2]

SYSCLK FPGA_HDMI_TD2-FPGA_AR_D8 FPGA_AR_D7 FPGA_AR_D6 FPGA_AR_D5 FPGA_AR_D4 FPGA_AR_D3 FPGA_AR_D2 FPGA_AR_D1/TX FPGA_AR_D0/RX L3 | VCC_1V

FPGA_Download--Interface(2) M[2~0]=101 JTAG Mode M[2~0]=111 Slave serial Mode Slave serial mode only supports .bin format document

In order to distinguish hardware version
Sample version：000
Official version： 001

TITLE: Design: | Check: Date: Vision: CC-BY-SA

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

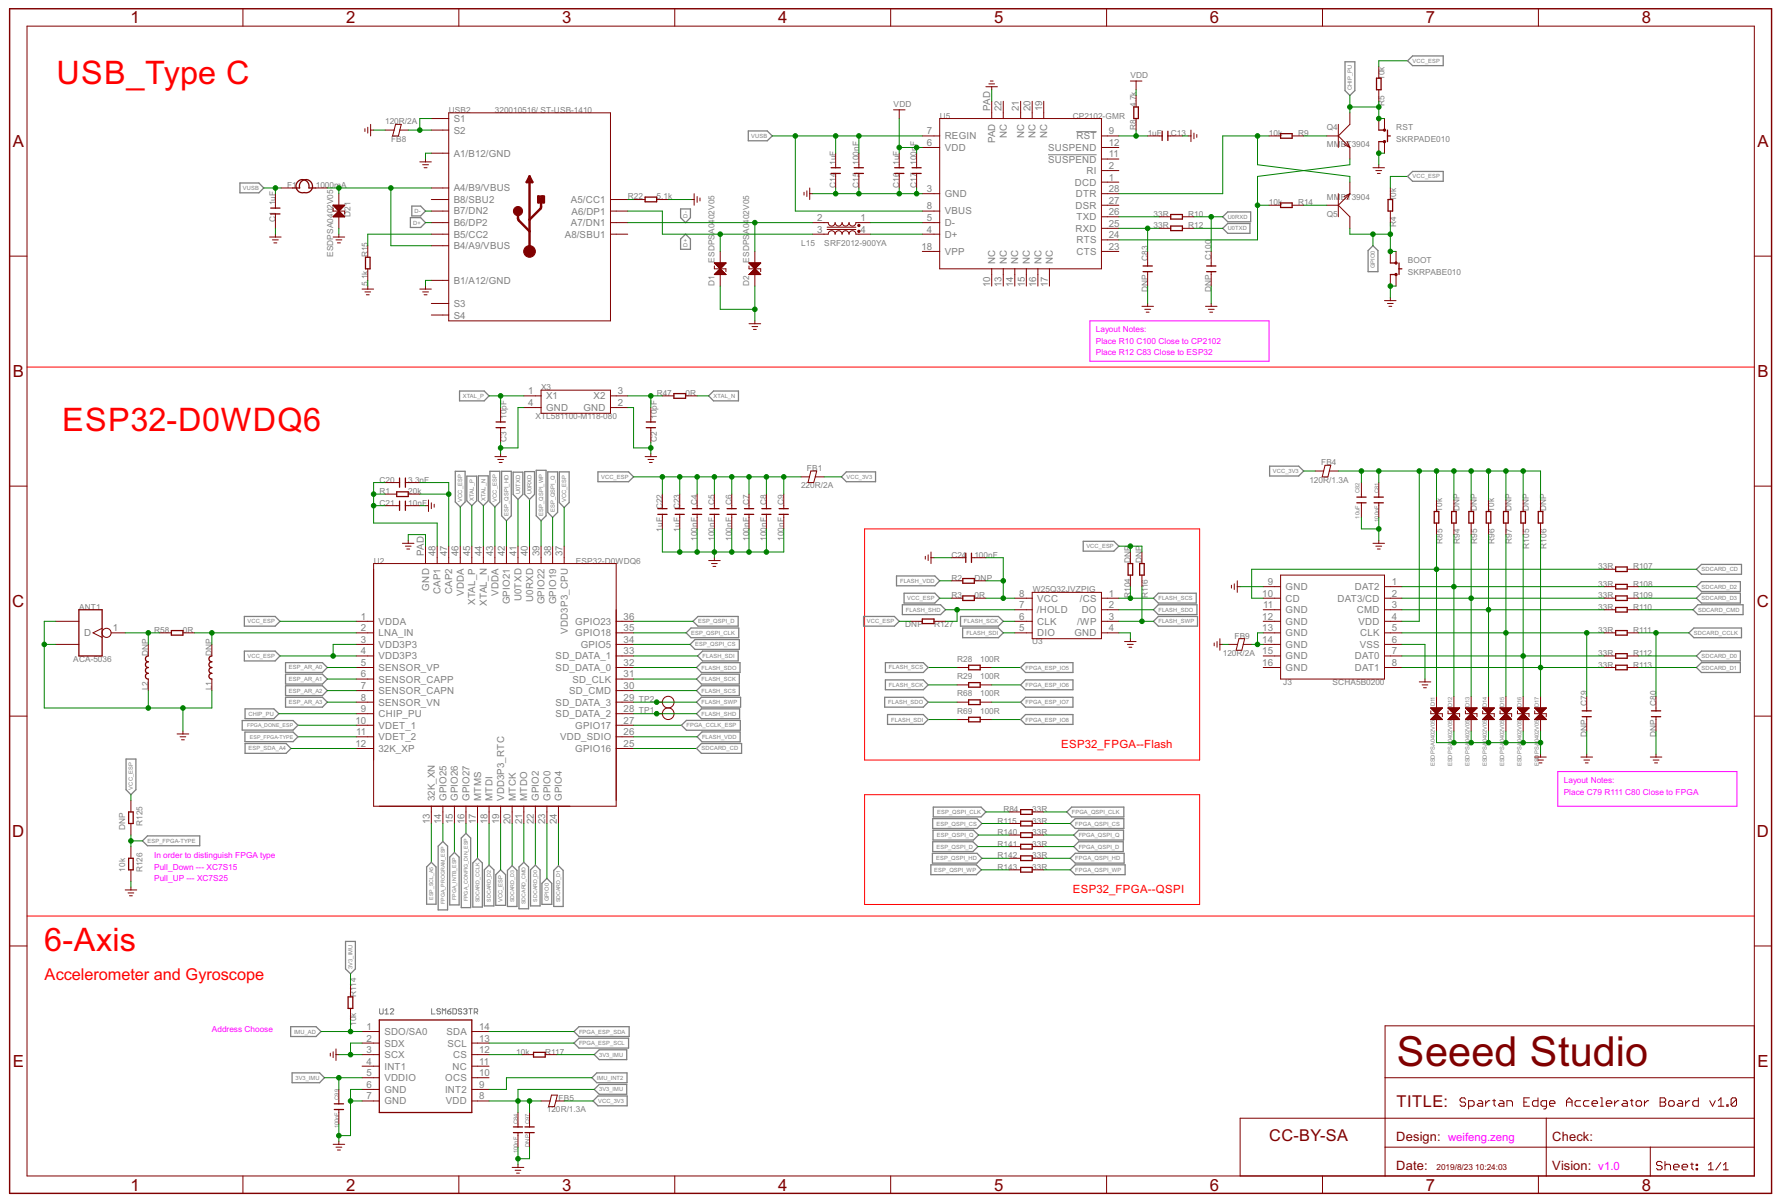
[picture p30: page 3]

Layout Notes: Place R10 C100 Close to CP2102 Place R12 C83 Close to ESP32

ESP_FPGA-TYPE 12 | FLASH_VDD

ESP_SDA_A4 | SDCARD_CD

Layout Notes: Place C79 R111 C80 Close to FPGA

ESP_FPGA-TYPE
In order to distinguish FPGA type
Pull_Down --- XC7S15 Pull_UP --- XC7S25

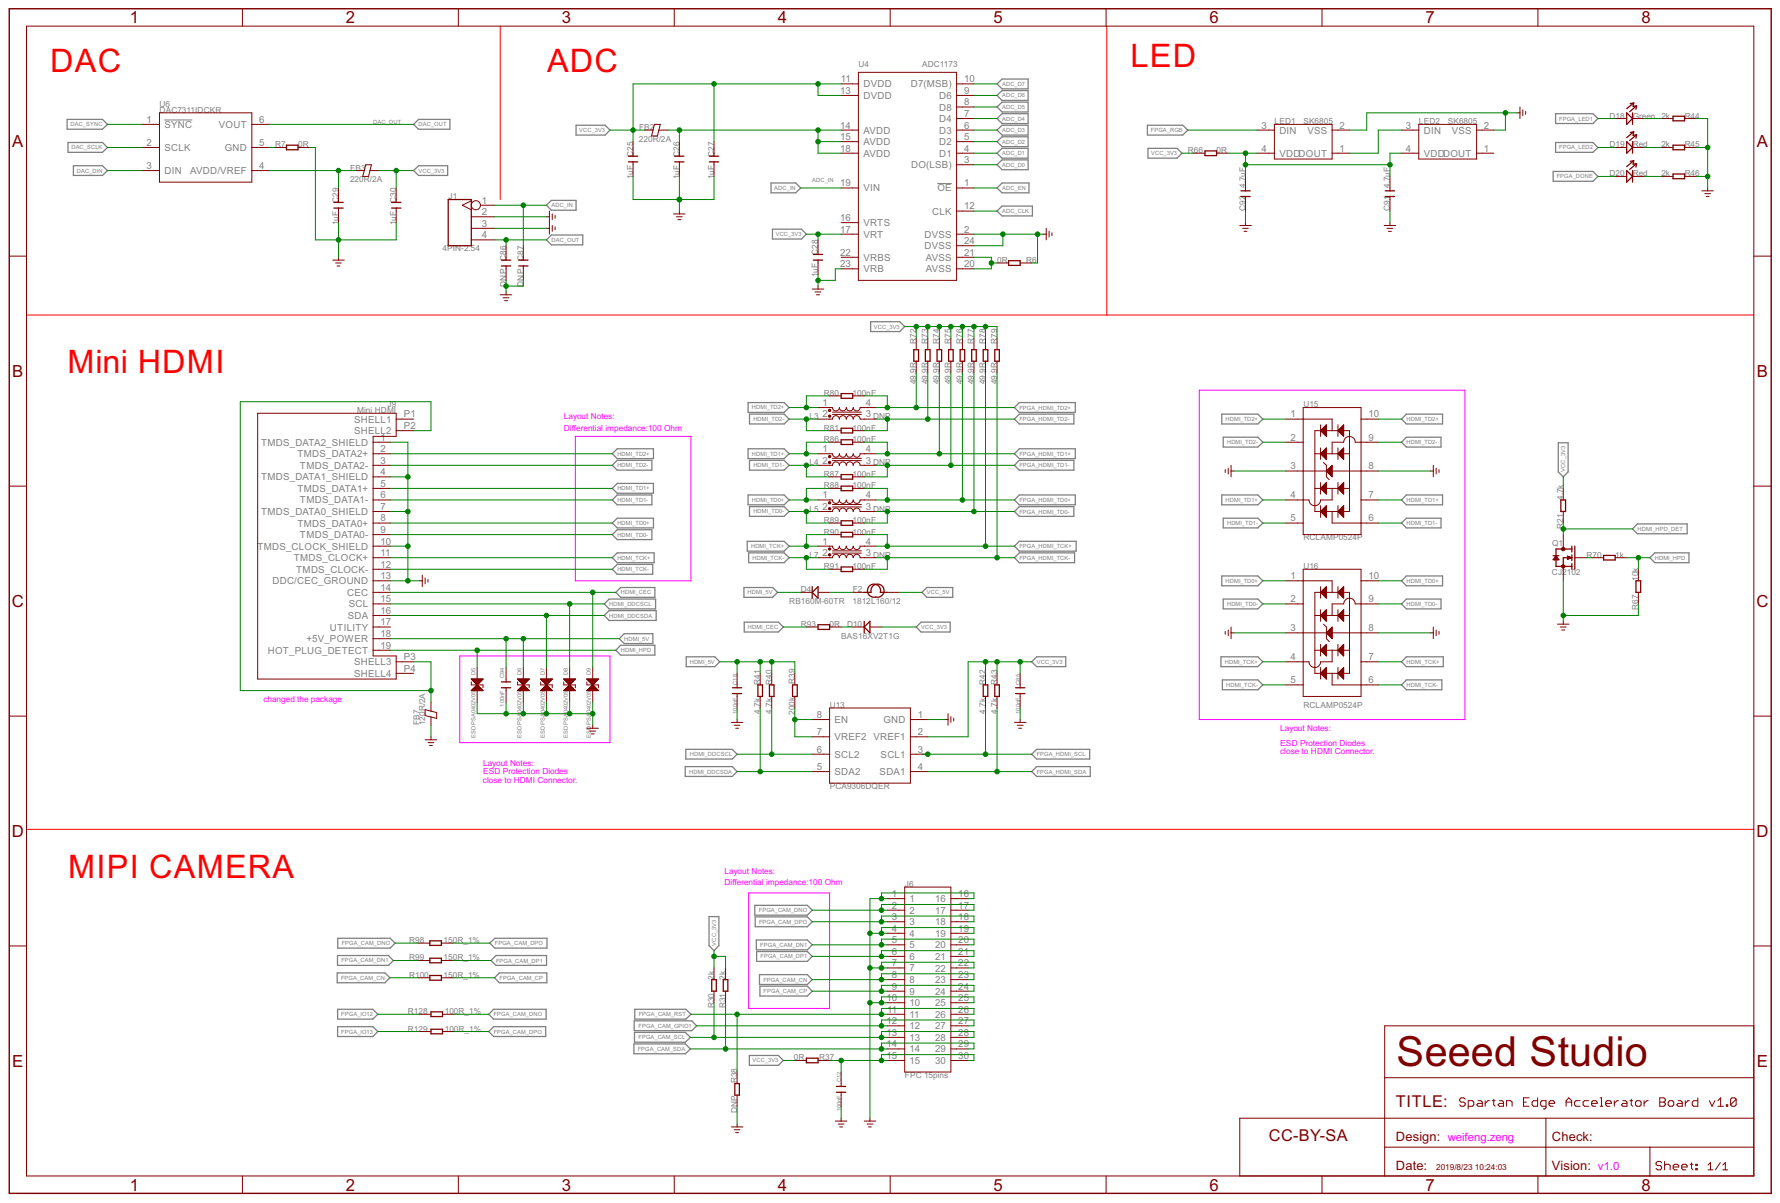
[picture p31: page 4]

2 3 | ADC_IN | ADC_CLK 2

close to HDMI Connector. ESD Protection Diodes

close to HDMI Connector.

FPGA_CAM_DNO | | 2 17
FPGA_CAM_DPO | 3 | 3 18 | 18

FPGA_CAM_CP | 10 | 9 24 | 25

FPGA_CAM_SDA | 14 15 | 14 29 | 29 30

TITLE: Design: | Check: Date: Vision: CC-BY-SA

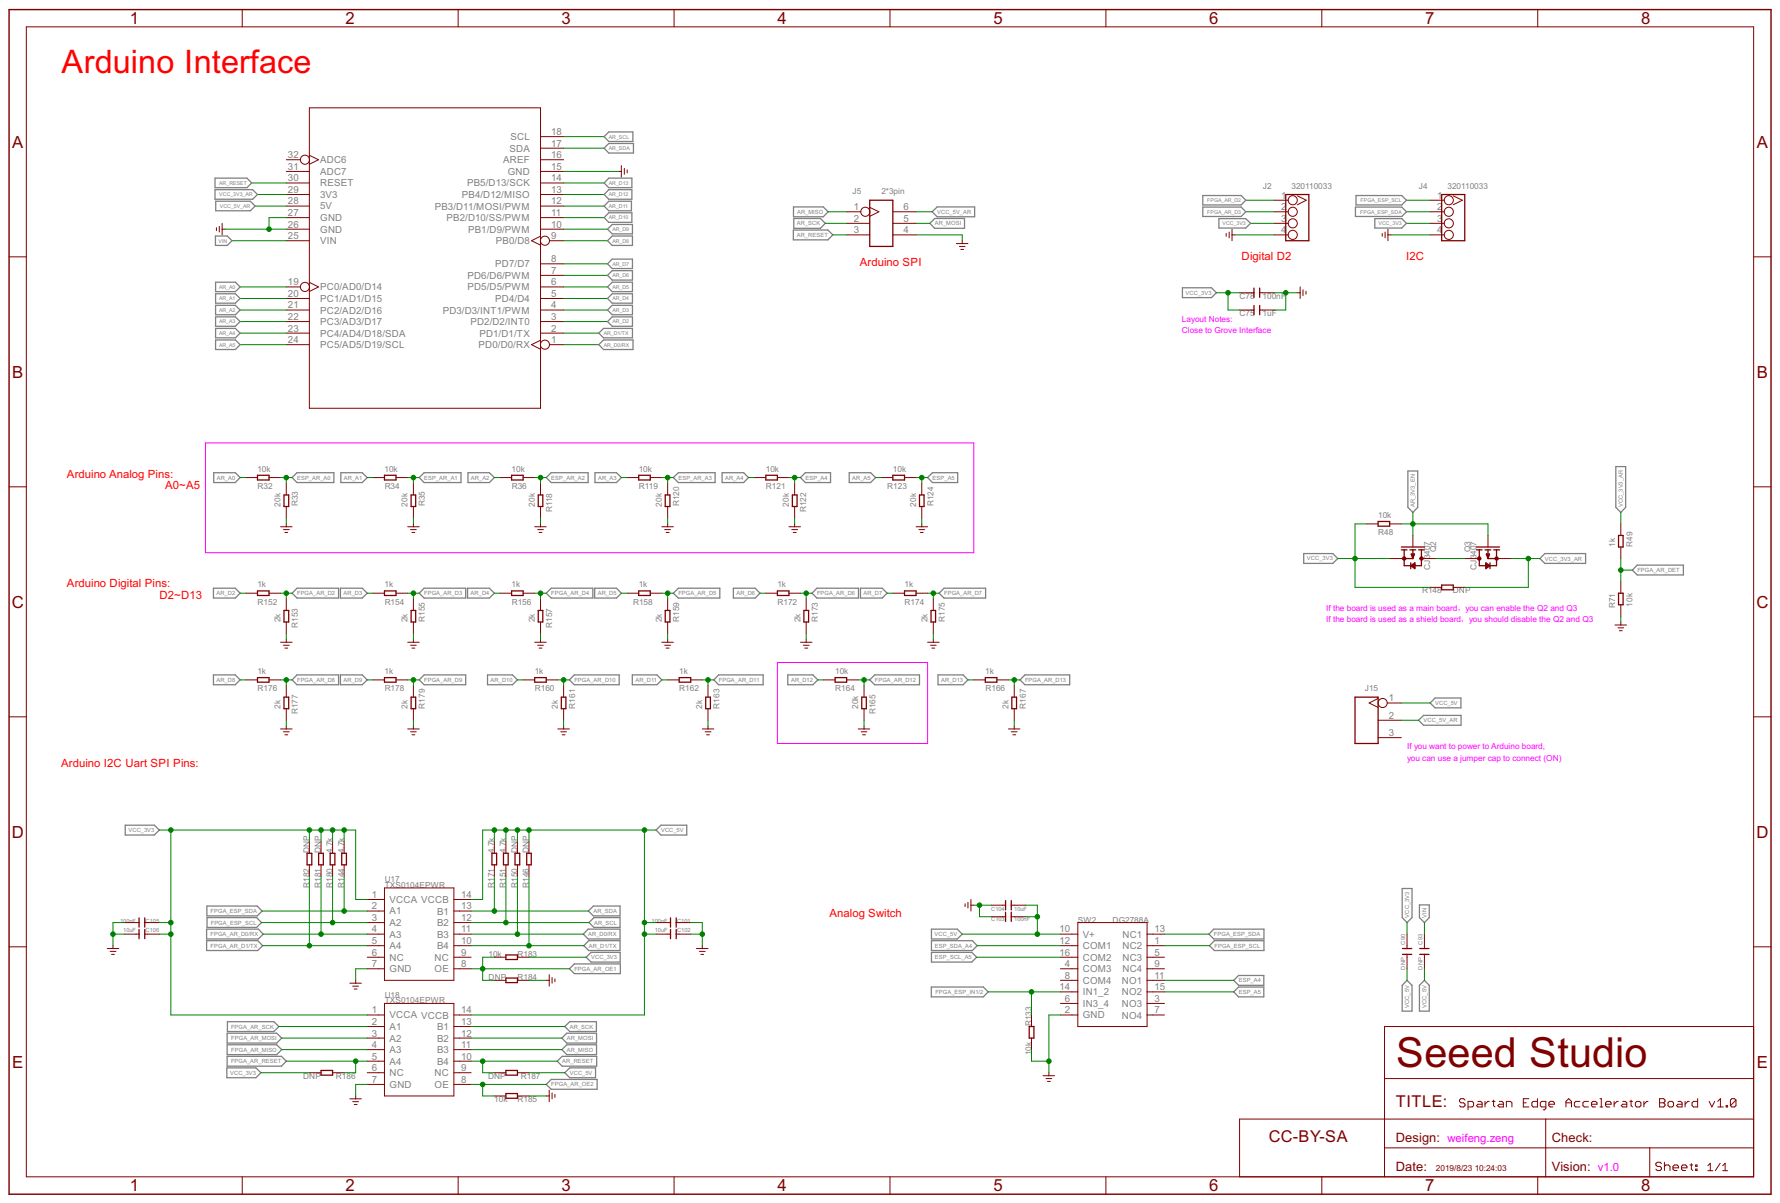
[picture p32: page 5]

1 2 | 1 FPGA_ESP_SCL FPGA_ESP_SDA 2

Layout Notes:
Close to Grove Interface

If the board is used as a main board，you can enable the Q2 and Q3
If the board is used as a shield board，you should disable the Q2 and Q3

If you want to power to Arduino board, you can use a jumper cap to connect (ON)

Arduino I2C Uart SPI Pins:

TITLE: Design: | Check: Date: Vision: CC-BY-SA

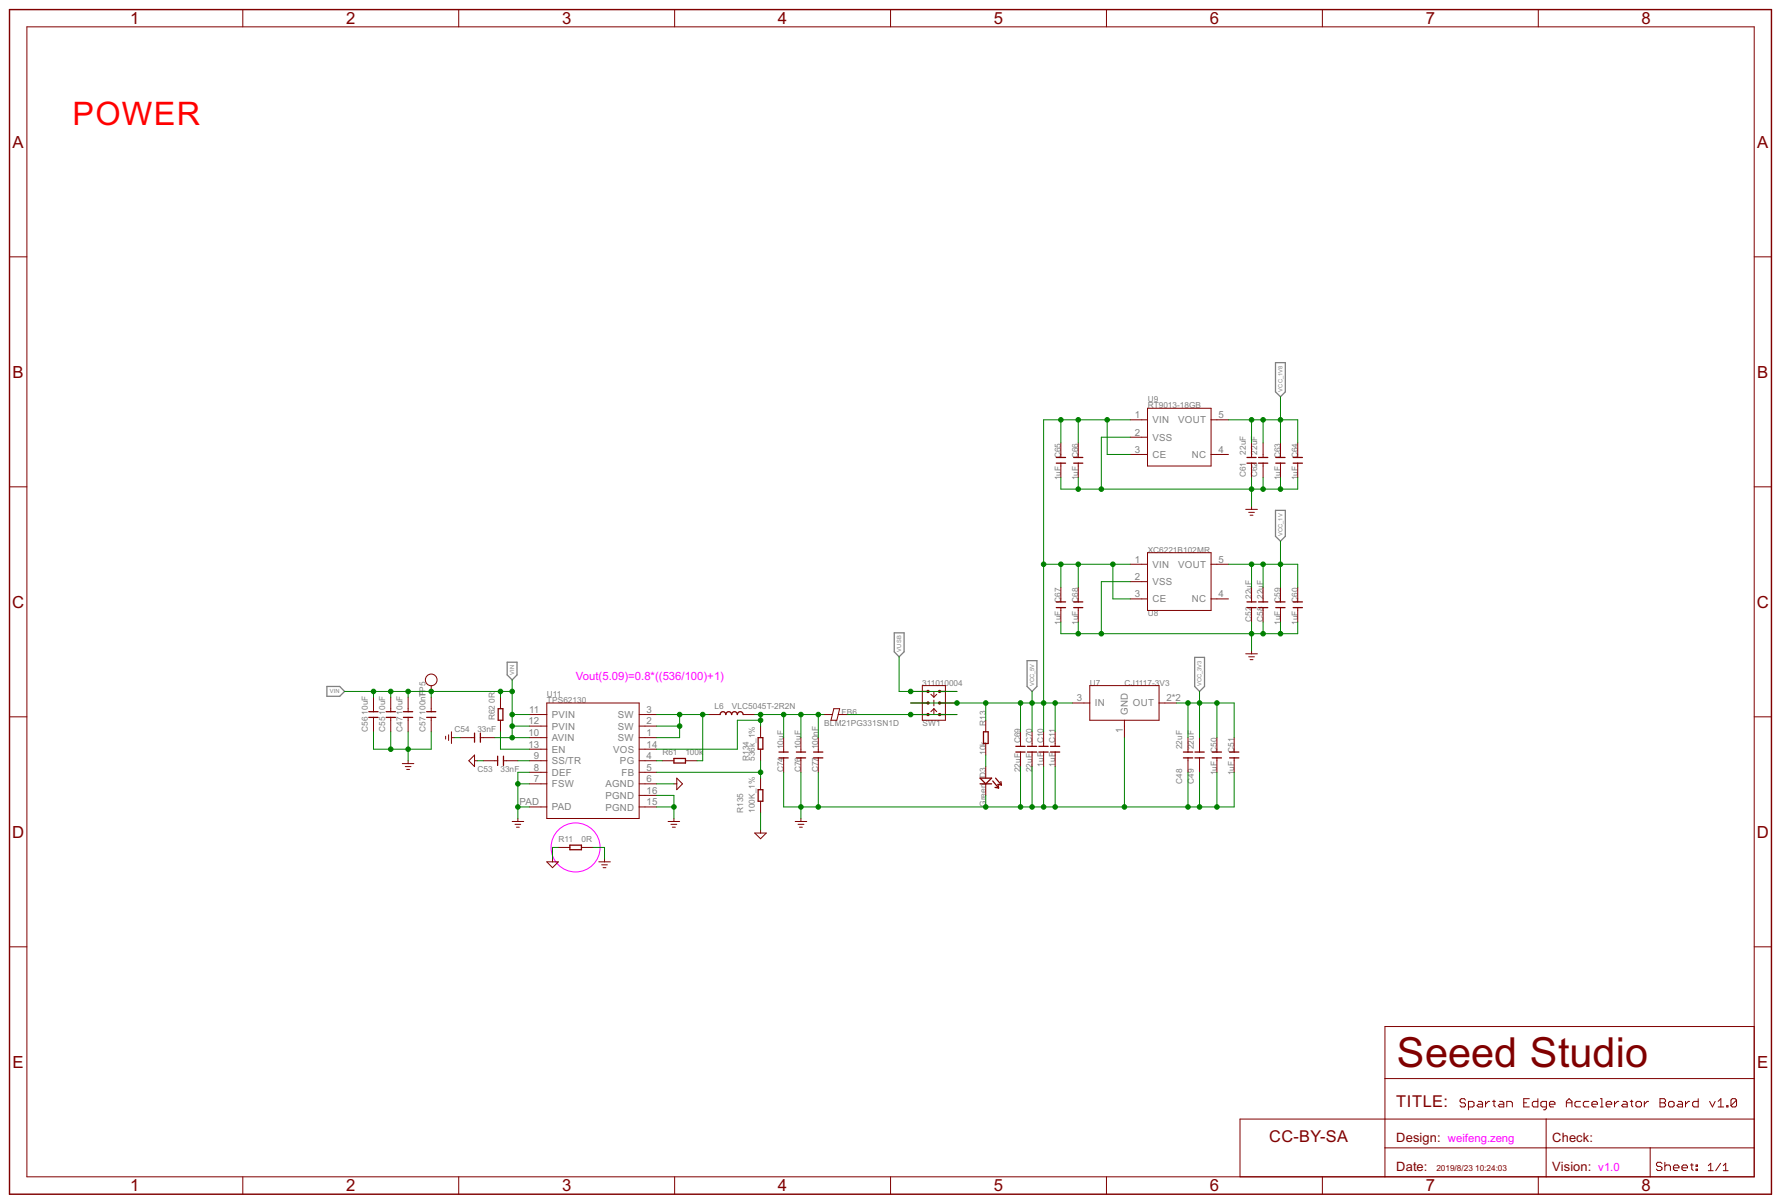
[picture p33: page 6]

TITLE: Design: | Check: Date: Vision: CC-BY-SA

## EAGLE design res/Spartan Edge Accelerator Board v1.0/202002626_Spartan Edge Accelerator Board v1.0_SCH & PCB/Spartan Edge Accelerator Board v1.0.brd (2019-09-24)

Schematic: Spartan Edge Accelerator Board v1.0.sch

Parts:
ANT1: ACA-5036; ANT3-SMD-5.2X3.7X0.7MM
BOOT: SKRPABE010; SW4P-SMD-4.5X3.2X2.5MM
BUTTON1, BUTTON2: BUTTON; SW4P-SMD-4.5X3.2X2.5MM
C1, C10, C11, C13, C14, C16, C22, C23, C25, C26, C27, C28, C29, C30, C31, C32, C33, C34, C35, C36, C37, C38, C39, C50, C51, C59, C60, C63, C64, C65, C66, C67, C68, C75: 1uF; C0402
C2, C3: 10pF; C0402
C4, C5, C6, C7, C8, C9, C12, C15, C17, C24, C72, C73, C78, C81, C84, C99, C101, C103, C105: 100nF; C0402
C18, C57, C77, C85, C94: 100nF; C0603
C20: 3.3nF; C0402
C21: 10nF; C0402
C40, C41, C42, C45, C48, C49, C52, C58, C61, C62, C69, C70: 22uF; C1206
C43, C44, C46: 470nF; C0402
C47, C55, C56, C74, C76: 10uF; C0805
C53, C54: 33nF; C0603
C71, C79, C80, C83, C86, C87, C95, C96, C98, C100: DNP; C0402
C82, C102, C104, C106: 10uF; C0603
C90, C93, C97: DNP; C0603
C91, C92: 4.7uF; C0603
D1, D2, D5, D6, D7, D8, D9, D11, D12, D13, D14, D15, D16, D17, D21: ESDPSA0402V05; ESD-0402
D3, D18: Green; LED-0402
D4: RB160M-60TR; SOD-123
D10: BAS16XV2T1G; SOD-523
D19, D20: Red; LED-0402
F1: 1000mA; F1206
F2: 1812L160/12; F1812
FB1, FB2, FB3: 220R/2A; F0603
FB4, FB5: 120R/1.3A; F0402
FB6: BLM21PG331SN1D; F0805
FB7, FB8, FB9: 120R/2A; F0603
FPGA_RST: BUTTON; SW4P-SMD-4.5X3.2X2.5MM
FR1, FR2, FR3, FR4, FR5, FR6: SEEEDSTUDIO-OPEN-SCH-FRAME-BIG; SEEEDSTUDIO-PCB-FRAME
J1: 4PIN-2.54; H4-2.54
J2, J4: 320110033; HW4-2.0
J3: SCHA5B0200; MICRO-SD9+7P-SMD-15X14.5X1.5
J5: 2*3pin; H2X3-2.54
J6: FPC 15pins; H2X15-SMD-1MM
J8: 6PIN-2.54; H6-2.54-C65D35MIL
J9: Mini HDMI; HDMI-19+4P-0.4-11.2X7.5MM
J10: DNP; H10-2.54
J15: HEADER-3P-2.54; H3-2.54
L1, L2: DNP; L0402
L3, L4, L5, L7: DNP; INT4-0.8-2X1.2MM
L6: VLC5045T-2R2N; INT2-SMD-4.8X4.8X3MM
L15: SRF2012-900YA; INT4-0.85-2X1.25X1.2MM
LED1, LED2: SK6805; LED-4P-SMD-2.7X2.4MM
Q1: CJ2102; SOT-323
Q2, Q3: CJ3407; SOT-23
Q4, Q5: MMBT3904; SOT-23
R1, R33, R35, R118, R120, R122, R124, R165: 20k; R0402
R2, R17, R20, R38, R94, R95, R97, R104, R105, R106, R116, R125, R127, R146, R147, R149, R150, R181, R182, R184, R186, R187: DNP; R0402
R3, R6, R7, R16, R23, R24, R25, R26, R27, R37, R47, R58, R66, R93: 0R; R0402
R4, R5, R9, R13, R14, R18, R19, R32, R34, R36, R48, R67, R71, R85, R96, R114, R117, R119, R121, R123, R126, R133, R145, R164, R183, R185: 10k; R0402
R8, R21, R40, R41, R42, R43, R53, R54, R55, R101, R102, R103, R144, R151, R171, R180: 4.7k; R0402
R10, R12, R84, R107, R108, R109, R110, R111, R112, R113, R115, R140, R141, R142, R143: 33R; R0402
R11, R62: 0R; R0603
R15, R22: 5.1k; R0402
R28, R29, R68, R69: 100R; R0402
R30, R31, R44, R45, R46, R153, R155, R157, R159, R161, R163, R167, R173, R175, R177, R179: 2k; R0402
R39: 200k; R0402
R49, R50, R51, R52, R56, R57, R65, R70, R82, R83, R92, R152, R154, R156, R158, R160, R162, R166, R172, R174, R176, R178: 1k; R0402
R59, R60, R63, R64, R130: 100k; R0402
R61: 100k; R0603
R72, R73, R74, R75, R76, R77, R78, R79: 49.9R; R0402
R80, R81, R86, R87, R88, R89, R90, R91: 100nF; R0603
R98, R99, R100: 150R_1%; R0402
R128, R129: 100R_1%; R0402
R134: 536k_1%; R0603
R135: 100K_1%; R0603
R148: DNP; R1206
RST: SKRPADE010; SW4P-SMD-4.5X3.2X2.5MM
SW1: 311010004; SW6-2.54-9.0X3.5X3.2+2.0MM
SW2: DG2788A; MINI-QFN16-0.4-2.6X1.8X0.55MM
SW4: SWITCH-5BIT-DSHP05TSGER; 10P-SMD-7.95X5.4X2.3MM
TP1, TP2: TEST-POINT-35; TP_3535
TP5: TEST-POINT'4545'; TP-D45MIL
U1: XC7S15-1FTGB196C; FTGB196-1.0-15X15X1.46MM
U2: ESP32-D0WDQ6; QFN48G-0.4-6X6MM
U3: W25Q32JVZPIG; SOIC8-1.27-5X4MM
U4: ADC1173; TSSOP24-0.65-7.8X4.4MM
U5: CP2102-GMR; QFN28
U6: DAC7311IDCKR; SC-70-6
U7: CJ1117-3V3; SOT-223
U8: XC6221B102MR; SOT-23-5
U9: RT9013-18GB; SOT-23-5
U10: Arduino pins; ARDUINO-32P
U11: TPS62130; VQFN16-0.5-3X3X1MM
U12: LSM6DS3TR; LGA14L_DOT_INDICATOR
U13: PCA9306DQER; X2SON8-0.35-1.4X1X0.37MM
U15, U16: RCLAMP0524P; ESD10P-0.5-2.5X1X0.58MM
U17, U18: TXS0104EPWR; TSSOP14-0.65-5X4.4MM
USB2: 320010516/ ST-USB-1410; USB2.0-TYPE-C
X2: O3225100MEDA4SC; X4-SMD-3.2X2.5X1MM
X3: XTL581100-M118-080; X4-SMD-2.5X2.0X1.0MM

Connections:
3V3_IMU: C84.1, C97.2, C99.1, FB5.2, R114.2, R117.2, U12.5 (VDDIO), U12.8 (VDD)
ADC_CLK: U1.C5 (IO_L6P_T0_34), U4.12 (CLK)
ADC_D0: U1.J3 (IO_L17N_T2_34), U4.3 (DO(LSB))
ADC_D1: U1.J2 (IO_L15P_T2_DQS_34), U4.4 (D1)
ADC_D2: U1.D12 (IO_L8P_T1_D11_14), U4.5 (D2)
ADC_D3: U1.E12 (IO_L7N_T1_D10_14), U4.6 (D3)
ADC_D4: U1.F12 (IO_L7P_T1_D09_14), U4.7 (D4)
ADC_D5: U1.C11 (IO_L6P_T0_FCS_B_14), U4.8 (D8)
ADC_D6: U1.H11 (IO_L13P_T2_MRCC_14), U4.9 (D6)
ADC_D7: U1.H12 (IO_L13N_T2_MRCC_14), U4.10 (D7(MSB))
ADC_EN: U1.J4 (IO_L17P_T2_34), U4.1 (!OE)
ADC_IN: C87.1, J1.1, U4.19 (VIN)
AGND: C53.1, R11.1, R135.2, U11.6 (AGND)
AR_3V3_EN: Q2.1 (G), Q3.1 (G), R48.1, U1.L13 (IO_L16N_T2_D31_14)
AR_A0: R32.2, U10.19 (PC0/AD0/D14)
AR_A1: R34.2, U10.20 (PC1/AD1/D15)
AR_A2: R36.2, U10.21 (PC2/AD2/D16)
AR_A3: R119.2, U10.22 (PC3/AD3/D17)
AR_A4: R121.2, U10.23 (PC4/AD4/D18/SDA)
AR_A5: R123.2, U10.24 (PC5/AD5/D19/SCL)
AR_D0/RX: R150.1, U10.1 (PD0/D0/RX), U17.11 (B3)
AR_D1/TX: R146.1, U10.2 (PD1/D1/TX), U17.10 (B4)
AR_D2: R152.2, U10.3 (PD2/D2/INT0)
AR_D3: R154.2, U10.4 (PD3/D3/INT1/PWM)
AR_D4: R156.2, U10.5 (PD4/D4)
AR_D5: R158.2, U10.6 (PD5/D5/PWM)
AR_D6: R172.2, U10.7 (PD6/D6/PWM)
AR_D7: R174.2, U10.8 (PD7/D7)
AR_D8: R176.2, U10.9 (PB0/D8)
AR_D9: R178.2, U10.10 (PB1/D9/PWM)
AR_D10: R160.2, U10.11 (PB2/D10/SS/PWM)
AR_D11: R162.2, U10.12 (PB3/D11/MOSI/PWM)
AR_D12: R164.2, U10.13 (PB4/D12/MISO)
AR_D13: R166.2, U10.14 (PB5/D13/SCK)
AR_MISO: J5.1, U18.11 (B3)
AR_MOSI: J5.5, U18.12 (B2)
AR_RESET: J5.3, R187.2, U10.30 (RESET), U18.10 (B4)
AR_SCK: J5.2, U18.13 (B1)
AR_SCL: R151.1, U10.18 (SCL), U17.12 (B2)
AR_SDA: R171.1, U10.17 (SDA), U17.13 (B1)
CHIP_PU: Q4.3 (C), R5.1, RST.1 (A0), RST.2 (A1), U2.9 (CHIP_PU)
D+: D1.2, L15.3, USB2.A6 (A6/DP1), USB2.B6 (B6/DP2)
D-: D2.2, L15.2, USB2.A7 (A7/DN1), USB2.B7 (B7/DN2)
DAC_DIN: U1.L1 (IO_L18N_T2_34), U6.3 (DIN)
DAC_OUT: C86.1, J1.4, U6.6 (VOUT)
DAC_SCLK: U1.M1 (IO_L18P_T2_34), U6.2 (SCLK)
DAC_SYNC: U1.N1 (IO_L20N_T3_34), U6.1 (!SYNC)
ESP_A4: R121.1, R122.1, SW2.11 (NO1)
ESP_A5: R123.1, R124.1, SW2.15 (NO2)
ESP_AR_A0: R32.1, R33.1, U2.5 (SENSOR_VP)
ESP_AR_A1: R34.1, R35.1, U2.6 (SENSOR_CAPP)
ESP_AR_A2: R36.1, R118.1, U2.7 (SENSOR_CAPN)
ESP_AR_A3: R119.1, R120.1, U2.8 (SENSOR_VN)
ESP_FPGA-TYPE: R125.1, R126.2, U2.11 (VDET_2)
ESP_QSPI_CLK: R84.2, U2.35 (GPIO18)
ESP_QSPI_CS: R115.2, U2.34 (GPIO5)
ESP_QSPI_D: R141.2, U2.36 (GPIO23)
ESP_QSPI_HD: R142.2, U2.42 (GPIO21)
ESP_QSPI_Q: R140.2, U2.38 (GPIO19)
ESP_QSPI_WP: R143.2, U2.39 (GPIO22)
ESP_SCL_A5: SW2.16 (COM2), U2.13 (32K_XN)
ESP_SDA_A4: SW2.12 (COM1), U2.12 (32K_XP)
FLASH_SCK: R29.2, U2.31 (SD_CLK), U3.6 (CLK)
FLASH_SCS: R28.2, R104.2, U2.30 (SD_CMD), U3.1 (/CS)
FLASH_SDI: R69.2, U2.33 (SD_DATA_1), U3.5 (DIO)
FLASH_SDO: R68.2, U2.32 (SD_DATA_0), U3.2 (DO)
FLASH_SHD: R127.2, TP1.T, U2.28 (SD_DATA_2), U3.7 (/HOLD)
FLASH_SWP: R116.2, TP2.T, U2.29 (SD_DATA_3), U3.3 (/WP)
FLASH_VDD: R2.2, U2.26 (VDD_SDIO)
FPGA_AR_D0/RX: R181.1, U1.A12 (IO_L4P_T0_D04_14), U17.4 (A3)
FPGA_AR_D1/TX: R182.1, U1.C12 (IO_L6N_T0_D08_VREF_14), U17.5 (A4)
FPGA_AR_D2: J2.1, R152.1, R153.1, U1.A10 (IO_L3N_T0_DQS_EMCCLK_14)
FPGA_AR_D3: J2.2, R154.1, R155.1, U1.B6 (IO_0_34)
FPGA_AR_D4: R156.1, R157.1, U1.A5 (IO_L4N_T0_34)
FPGA_AR_D5: R158.1, R159.1, U1.B5 (IO_L4P_T0_34)
FPGA_AR_D6: R172.1, R173.1, U1.A4 (IO_L2P_T0_34)
FPGA_AR_D7: R174.1, R175.1, U1.A3 (IO_L2N_T0_34)
FPGA_AR_D8: R176.1, R177.1, U1.B3 (IO_L3P_T0_DQS_34)
FPGA_AR_D9: R178.1, R179.1, U1.A2 (IO_L3N_T0_DQS_34)
FPGA_AR_D10: R160.1, R161.1, U1.B2 (IO_L5P_T0_34)
FPGA_AR_D11: R162.1, R163.1, U1.B1 (IO_L5N_T0_34)
FPGA_AR_D12: R164.1, R165.1, U1.H1 (IO_L14N_T2_SRCC_34)
FPGA_AR_D13: R166.1, R167.1, U1.H2 (IO_L14P_T2_SRCC_34)
FPGA_AR_DET: R49.2, R71.2, U1.B11 (IO_L1P_T0_D00_MOSI_14)
FPGA_AR_MISO: U1.L5 (IO_25_34), U18.4 (A3)
FPGA_AR_MOSI: U1.M5 (IO_L23P_T3_34), U18.3 (A2)
FPGA_AR_OE1: R183.2, R184.2, U1.N4 (IO_L24N_T3_34), U17.8 (OE)
FPGA_AR_OE2: R185.2, U1.M3 (IO_L19P_T3_34), U18.8 (OE)
FPGA_AR_RESET: R186.1, U1.K4 (IO_L16P_T2_34), U18.5 (A4)
FPGA_AR_SCK: U1.H13 (IO_L14P_T2_SRCC_14), U18.2 (A1)
FPGA_CAM_CN: J6.8, J6.23, R100.1, U1.F11 (IO_L12N_T1_MRCC_14)
FPGA_CAM_CP: J6.9, J6.24, R100.2, U1.G11 (IO_L12P_T1_MRCC_14)
FPGA_CAM_DN1: J6.5, J6.20, R99.1, U1.P11 (IO_L24N_T3_D16_14)
FPGA_CAM_DNO: J6.2, J6.17, R98.1, R128.1, U1.J12 (IO_L17N_T2_D29_14)
FPGA_CAM_DP1: J6.6, J6.21, R99.2, U1.P10 (IO_L24P_T3_D17_14)
FPGA_CAM_DPO: J6.3, J6.18, R98.2, R129.1, U1.J11 (IO_L17P_T2_D30_14)
FPGA_CAM_GPIO1: J6.12, J6.27, U1.M11 (IO_L20P_T3_D24_14)
FPGA_CAM_RST: J6.11, J6.26, R38.1, U1.M12 (IO_L20N_T3_D23_14)
FPGA_CAM_SCL: J6.13, J6.28, R30.1, U1.K11 (IO_L19P_T3_D26_14)
FPGA_CAM_SDA: J6.14, J6.29, R31.1, U1.K12 (IO_L19N_T3_D25_VREF_14)
FPGA_CCLK: R24.2, U1.A8 (CCLK_0)
FPGA_CCLK_ESP: R24.1, U2.27 (GPIO17)
FPGA_CONFIG_DIN: R27.2, U1.B12 (IO_L1N_T0_D01_DIN_14)
FPGA_CONFIG_DIN_ESP: R27.1, U2.16 (GPIO27)
FPGA_DONE: D20.+, R26.2, R55.2, U1.P9 (DONE_0)
FPGA_DONE_ESP: R26.1, U2.10 (VDET_1)
FPGA_ESP_IN1/2: R133.1, SW2.14 (IN1_2), U1.H3 (IO_L13N_T2_MRCC_34)
FPGA_ESP_IO5: R28.1, U1.E13 (IO_L10N_T1_D15_14)
FPGA_ESP_IO6: R29.1, U1.F14 (IO_L9N_T1_DQS_D13_14)
FPGA_ESP_IO7: R68.1, U1.F13 (IO_L10P_T1_D14_14)
FPGA_ESP_IO8: R69.1, U1.G14 (IO_L9P_T1_DQS_14)
FPGA_ESP_SCL: J4.1, R180.1, SW2.1 (NC2), U1.P12 (IO_L22P_T3_D21_14), U12.13 (SCL), U17.3 (A2)
FPGA_ESP_SDA: J4.2, R144.1, SW2.13 (NC1), U1.P13 (IO_L22N_T3_D20_14), U12.14 (SDA), U17.2 (A1)
FPGA_HDMI_SCL: R42.2, U1.F3 (IO_L8P_T1_34), U13.3 (SCL1)
FPGA_HDMI_SDA: R43.2, U1.F2 (IO_L8N_T1_34), U13.4 (SDA1)
FPGA_HDMI_TCK+: L7.4 (2), R78.2, R90.2, U1.G4 (IO_L12P_T1_MRCC_34)
FPGA_HDMI_TCK-: L7.3, R79.2, R91.2, U1.F4 (IO_L12N_T1_MRCC_34)
FPGA_HDMI_TD0+: L5.4 (2), R76.2, R88.2, U1.G1 (IO_L9P_T1_DQS_34)
FPGA_HDMI_TD0-: L5.3, R77.2, R89.2, U1.F1 (IO_L9N_T1_DQS_34)
FPGA_HDMI_TD1+: L4.4 (2), R74.2, R86.2, U1.E2 (IO_L10P_T1_34)
FPGA_HDMI_TD1-: L4.3, R75.2, R87.2, U1.D2 (IO_L10N_T1_34)
FPGA_HDMI_TD2+: L3.4 (2), R72.2, R80.2, U1.D1 (IO_L11P_T1_SRCC_34)
FPGA_HDMI_TD2-: L3.3, R73.2, R81.2, U1.C1 (IO_L11N_T1_SRCC_34)
FPGA_INTB: R25.2, R54.2, U1.P8 (INIT_B_0)
FPGA_INTB_ESP: R25.1, U2.15 (GPIO26)
FPGA_IO0: J10.1, U1.N14 (IO_L21P_T3_DQS_14)
FPGA_IO1: J10.2, U1.M14 (IO_L21N_T3_DQS_D22_14)
FPGA_IO2: J10.3, U1.C4 (IO_L6N_T0_VREF_34)
FPGA_IO3: J10.4, U1.B13 (IO_L5P_T0_D06_14)
FPGA_IO4: J10.5, U1.N10 (IO_L23P_T3_D19_14)
FPGA_IO5: J10.6, U1.M10 (IO_25_14)
FPGA_IO6: J10.7, U1.B14 (IO_L5N_T0_D07_14)
FPGA_IO7: J10.8, U1.D3 (IO_L1P_T0_34)
FPGA_IO8: J10.9, U1.P5 (IO_L24P_T3_34)
FPGA_IO9: J10.10, U1.E11 (IO_0_14)
FPGA_IO10: BUTTON1.1 (A0), BUTTON1.2 (A1), C96.1, R102.2, U1.C3 (IO_L1N_T0_34)
FPGA_IO11: BUTTON2.1 (A0), BUTTON2.2 (A1), C98.1, R103.2, U1.M4 (IO_L23N_T3_34)
FPGA_IO12: R128.2, U1.C10 (IO_L2N_T0_D03_14)
FPGA_IO13: R129.2, U1.D10 (IO_L2P_T0_D02_14)
FPGA_K1: R64.1, SW4.1, U1.M2 (IO_L19N_T3_VREF_34)
FPGA_K2: R63.1, SW4.2, U1.L2 (IO_L22N_T3_34)
FPGA_K3: R60.1, SW4.3, U1.L3 (IO_L22P_T3_34)
FPGA_K4: R59.1, SW4.4, U1.K3 (IO_L16N_T2_34)
FPGA_LED1: D18.+, U1.J1 (IO_L15N_T2_DQS_34)
FPGA_LED2: D19.+, U1.A13 (IO_L4N_T0_D05_14)
FPGA_M0: R57.2, U1.M7 (M0_0)
FPGA_M1: R130.1, SW4.5, U1.M8 (M1_0)
FPGA_M2: R56.2, U1.M9 (M2_0)
FPGA_PROGRAM: R23.2, R53.2, U1.L7 (PROGRAM_B_0)
FPGA_PROGRAM_ESP: R23.1, U2.14 (GPIO25)
FPGA_QSPI_CLK: R84.1, U1.H14 (IO_L14N_T2_SRCC_14)
FPGA_QSPI_CS: R115.1, U1.M13 (IO_L15P_T2_DQS_RDWR_B_14)
FPGA_QSPI_D: R141.1, U1.P2 (IO_L20P_T3_34)
FPGA_QSPI_HD: R142.1, U1.D13 (IO_L8N_T1_D12_14)
FPGA_QSPI_Q: R140.1, U1.L14 (IO_L15N_T2_DQS_DOUT_CSO_B_14)
FPGA_QSPI_WP: R143.1, U1.J13 (IO_L18P_T2_D28_14)
FPGA_RGB: LED1.3 (DIN), U1.N11 (IO_L23N_T3_D18_14)
FPGA_RST: C95.1, FPGA_RST.1 (A0), FPGA_RST.2 (A1), R101.2, U1.D14 (IO_L11P_T1_SRCC_14)
FPGA_TCK: J8.4, U1.A7 (TCK_0)
FPGA_TDI: J8.6, U1.P7 (TDI_0)
FPGA_TDO: J8.5, U1.P6 (TDO_0)
FPGA_TMS: J8.3, U1.M6 (TMS_0)
GND: ANT1.2 (GND1), ANT1.3 (GND2), BOOT.3 (B0), BOOT.4 (B1), BUTTON1.3 (B0), BUTTON1.4 (B1), BUTTON2.3 (B0), BUTTON2.4 (B1), C1.1, C2.1, C3.1, C4.2, C5.2, C6.2, C7.2, C8.2, C9.2, C10.2, C11.2, C12.2, C13.1, C14.1, C15.1, C16.1, C17.1, C18.1, C21.2, C22.2, C23.2, C24.2, C25.2, C26.2, C27.2, C28.2, C29.2, C30.2, C31.2, C32.2, C33.2, C34.2, C35.2, C36.2, C37.2, C38.2, C39.2, C40.2, C41.2, C42.2, C43.2, C44.2, C45.2, C46.2, C47.1, C48.1, C49.1, C50.2, C51.2, C52.1, C54.1, C55.1, C56.1, C57.1, C58.1, C59.2, C60.2, C61.1, C62.1, C63.2, C64.2, C65.2, C66.2, C67.2, C68.2, C69.1, C70.1, C71.2, C72.2, C73.2, C74.1, C75.2, C76.1, C77.1, C78.2, C79.2, C80.2, C81.2, C82.1, C83.2, C84.2, C85.1, C86.2, C87.2, C91.1, C92.1, C94.1, C95.2, C96.2, C97.1, C98.2, C99.2, C100.2, C101.1, C102.2, C103.1, C104.2, C105.2, C106.1, D1.1, D2.1, D3.-, D5.1, D6.1, D7.1, D8.1, D9.1, D11.1, D12.1, D13.1, D14.1, D15.1, D16.1, D17.1, D21.2, FB7.1, FB8.2, FB9.2, FPGA_RST.3 (B0), FPGA_RST.4 (B1), J1.2, J1.3, J2.4, J3.6 (VSS), J3.9 (GND), J4.4, J5.4, J6.1, J6.4, J6.7, J6.10, J6.16, J6.19, J6.22, J6.25, J8.2, J9.1 (TMDS_DATA2_SHIELD), J9.4 (TMDS_DATA1_SHIELD), J9.7 (TMDS_DATA0_SHIELD), J9.10 (TMDS_CLOCK_SHIELD), J9.13 (DDC/CEC_GROUND), L1.1, L2.1, LED1.2 (VSS), LED2.2 (VSS), Q1.2 (S), R6.1, R7.2, R11.2, R15.2, R19.1, R20.1, R22.2, R33.2, R35.2, R38.2, R44.1, R45.1, R46.1, R59.2, R60.2, R63.2, R64.2, R65.2, R67.1, R71.1, R118.2, R120.2, R122.2, R124.2, R126.1, R130.2, R133.2, R145.1, R149.1, R153.2, R155.2, R157.2, R159.2, R161.2, R163.2, R165.2, R167.2, R173.2, R175.2, R177.2, R179.2, R184.1, R185.1, RST.3 (B0), RST.4 (B1), SW2.2 (GND), U1.A1 (GND), U1.A6 (GND), U1.A9 (GND), U1.A11 (GND), U1.A14 (GND), U1.B4 (GND), U1.B7 (GND), U1.B8 (NC), U1.B9 (GND), U1.C2 (GND), U1.C6 (GND), U1.C7 (GND), U1.C8 (GND), U1.C9 (GND), U1.C13 (GND), U1.D5 (GND), U1.D7 (GND), U1.D9 (GND), U1.D11 (GND), U1.E1 (GND), U1.E3 (GND), U1.E6 (GND), U1.E8 (GND), U1.E10 (GND), U1.E14 (GND), U1.F5 (GND), U1.F7 (NC), U1.F9 (GND), U1.G3 (GND), U1.G6 (GND), U1.G7 (NC), U1.G8 (NC), U1.G10 (GND), U1.G12 (GND), U1.H5 (GND), U1.H7 (NC), U1.H8 (NC), U1.H9 (GND), U1.J6 (GND), U1.J7 (DXN_0), U1.J8 (DXP_0), U1.J10 (GND), U1.K1 (GND), U1.K5 (GND), U1.K7 (GND), U1.K9 (GND), U1.K14 (GND), U1.L4 (GND), U1.L6 (GND), U1.L8 (GND), U1.L10 (GND), U1.L11 (GND), U1.N3 (GND), U1.N5 (GND), U1.N9 (GND), U1.N12 (GND), U1.P1 (GND), U1.P14 (GND), U2.PAD (GND), U3.4 (GND), U4.2 (DVSS), U4.23 (VRB), U4.24 (DVSS), U5.3 (GND), U5.PAD, U7.1 (GND), U8.2 (VSS), U9.2 (VSS), U10.15 (GND), U10.26 (GND), U10.27 (GND), U11.7 (FSW), U11.8 (DEF), U11.15 (PGND), U11.16 (PGND), U11.PAD, U12.2 (SDX), U12.3 (SCX), U12.6 (GND), U12.7 (GND), U13.1 (GND), U15.3, U15.8, U16.3, U16.8, U17.7 (GND), U18.7 (GND), USB2.A1_B12 (A1/B12/GND), USB2.B1_A12 (B1/A12/GND), X2.2 (GND), X3.2 (GND), X3.4 (GND)
GPIO0: BOOT.1 (A0), BOOT.2 (A1), Q5.3 (C), R4.1, U2.23 (GPIO0)
HDMI_5V: C18.2, C94.2, D4.-, D6.2, J9.18 (+5V_POWER), R39.1, R40.1, R41.1
HDMI_CEC: D9.2, J9.14 (CEC), R93.2, U1.E4 (IO_L7P_T1_34)
HDMI_DDCSCL: D8.2, J9.15 (SCL), R40.2, U13.6 (SCL2)
HDMI_DDCSDA: D7.2, J9.16 (SDA), R41.2, U13.5 (SDA2)
HDMI_HPD: D5.2, J9.19 (HOT_PLUG_DETECT), R67.2, R70.1
HDMI_HPD_DET: Q1.3 (D), R21.1, U1.D4 (IO_L7N_T1_34)
HDMI_TCK+: J9.11 (TMDS_CLOCK+), L7.1, R90.1, U16.4, U16.7
HDMI_TCK-: J9.12 (TMDS_CLOCK-), L7.2 (4), R91.1, U16.5, U16.6
HDMI_TD0+: J9.8 (TMDS_DATA0+), L5.1, R88.1, U16.1, U16.10
HDMI_TD0-: J9.9 (TMDS_DATA0-), L5.2 (4), R89.1, U16.2, U16.9
HDMI_TD1+: J9.5 (TMDS_DATA1+), L4.1, R86.1, U15.4, U15.7
HDMI_TD1-: J9.6 (TMDS_DATA1-), L4.2 (4), R87.1, U15.5, U15.6
HDMI_TD2+: J9.2 (TMDS_DATA2+), L3.1, R80.1, U15.1, U15.10
HDMI_TD2-: J9.3 (TMDS_DATA2-), L3.2 (4), R81.1, U15.2, U15.9
IMU_AD: R114.1, U1.J14 (IO_L18N_T2_D27_14), U12.1 (SDO/SA0)
IMU_INT2: U1.L12 (IO_L16P_T2_CSI_B_14), U12.9 (INT2)
unnamed: Q2.3 (D), Q3.3 (D)
unnamed: C2.2, R47.2, X3.3 (X2)
unnamed: R22.1, USB2.A5 (A5/CC1)
unnamed: R16.1, X2.3 (OUT)
unnamed: R15.1, USB2.B5 (B5/CC2)
unnamed: R117.1, U12.12 (CS)
unnamed: C12.1, J6.15, J6.30, R37.1
unnamed: R10.2, U5.26 (TXD)
unnamed: D10.-, R93.1
unnamed: C20.2, R1.2, U2.47 (CAP2)
unnamed: C20.1, C21.1, R1.1, U2.48 (CAP1)
unnamed: L1.2, R58.2, U2.2 (LNA_IN)
unnamed: ANT1.1 (D), L2.2, R58.1
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

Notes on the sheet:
Vout(5.09)=0.8*((536/100)+1)
ESP32_FPGA--Program
FPGA_Crystal
FPGA_Download--Interface(2)
M[2~0]=101 JTAG Mode
M[2~0]=111 Slave serial Mode
Slave serial mode only supports .bin format document
Differential impedance:100 Ohm
ESD Protection Diodes close to HDMI Connector.
Close to Grove Interface
Layout Notes:
Place C79 R111 C80 Close to FPGA
Address Choose
Place R10 C100 Close to CP2102
Place R12 C83 Close to ESP32
In order to distinguish FPGA type
In order to distinguish hardware version
Sample version：000
changed the package
If you want to power to Arduino board,
you can use a jumper cap to connect (ON)
If the board is used as a main board，you can enable the Q2 and Q3
If the board is used as a shield board，you should disable the Q2 and Q3
v1.0
Initial Version
2019.08.08
weifeng.zeng
Official version： 001
Pull_Down --- XC7S15
Pull_UP --- XC7S25

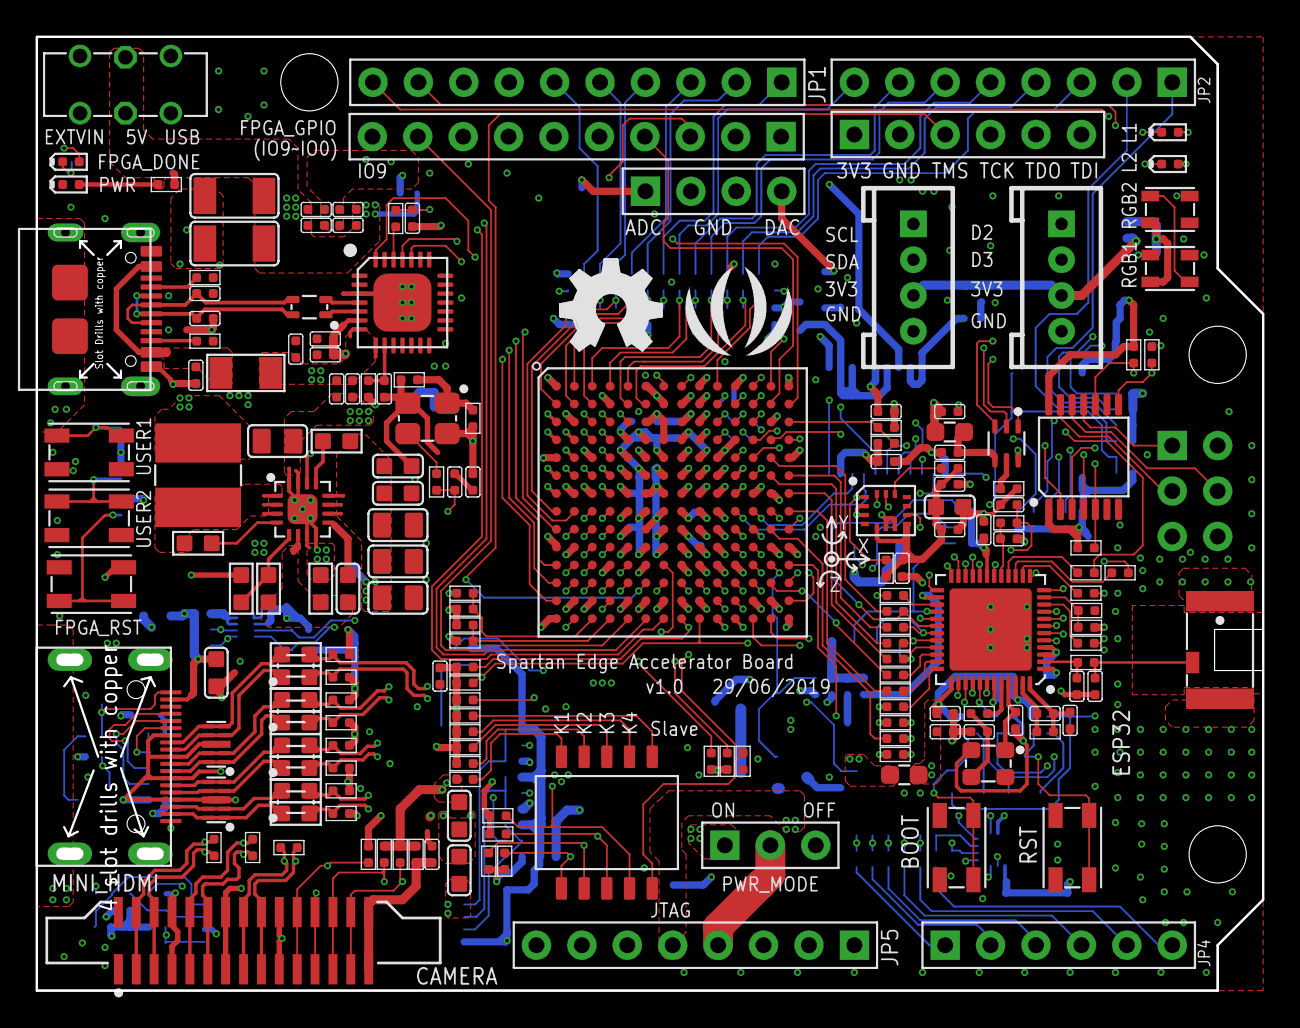
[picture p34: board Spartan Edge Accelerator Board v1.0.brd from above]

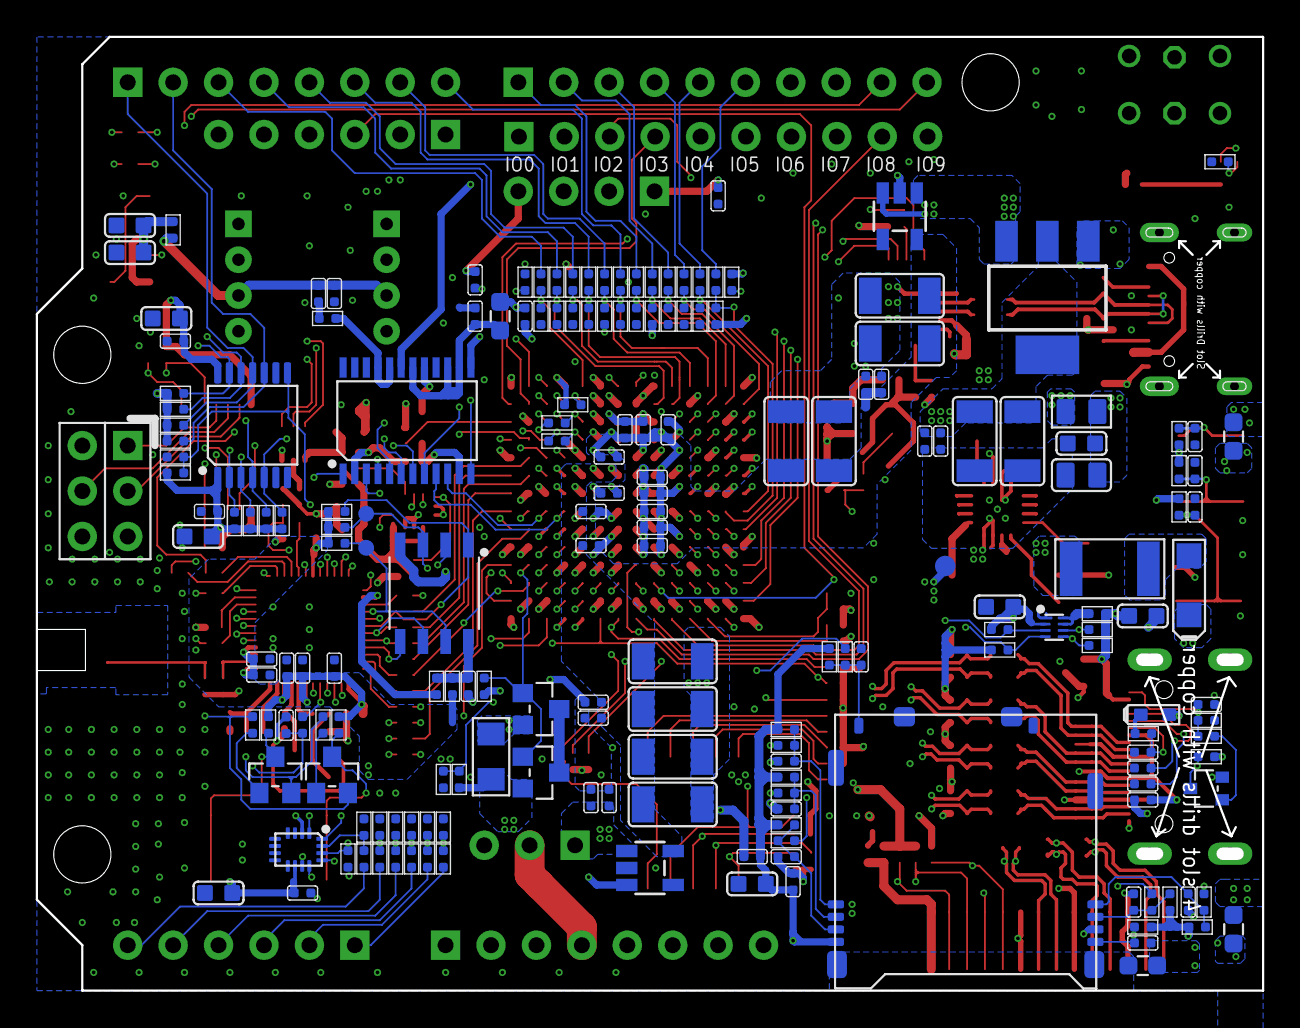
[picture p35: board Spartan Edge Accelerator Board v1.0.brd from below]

Board: 6 copper layers, 68.6 x 53.3 mm, 378 parts (192 on the bottom side), 266 nets.

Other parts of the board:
U$64: SEEED-SILK-TNAME-280*268MIL
U$65: OSHW_FILLX200_NOTEXT_TNAME

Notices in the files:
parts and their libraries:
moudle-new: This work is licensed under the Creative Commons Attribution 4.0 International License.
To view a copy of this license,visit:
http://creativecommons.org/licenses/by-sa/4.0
